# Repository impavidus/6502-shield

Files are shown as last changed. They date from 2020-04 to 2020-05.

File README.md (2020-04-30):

# 6502-shield

An Arduino shield that provides a 6502 cpu, ram, rom, and pio compactly.

## Project Status

I'm about to order the first prototype PCBs from OSH Park.  That means this PCB is completely untested and quite likely may burst into flames when powered on.  However, I am by no means here to tell you how to live your life so if you want to make one... =)

## Introduction

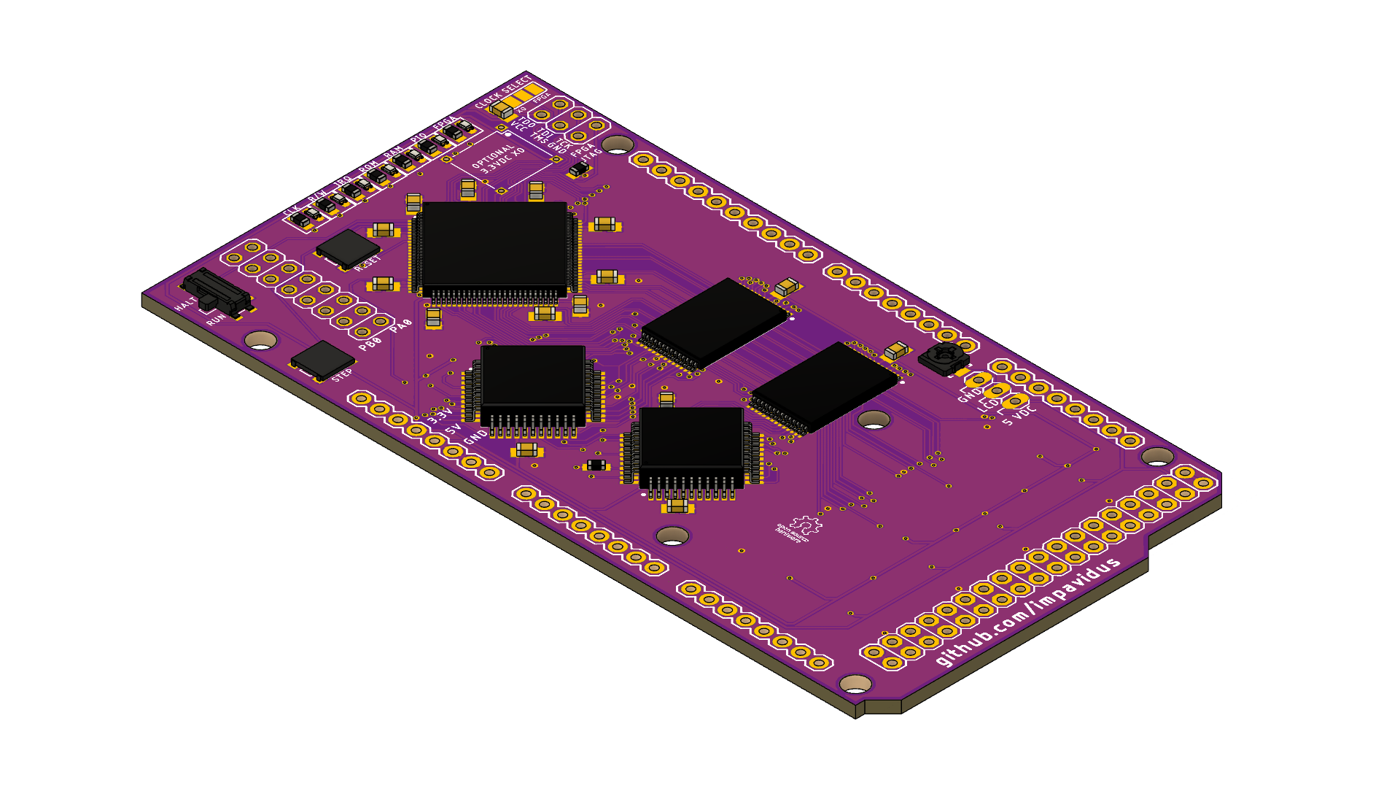
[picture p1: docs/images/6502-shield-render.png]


The 6502 shield provides (err will provide) most of the major components needed to implement a 6502 based computer.  Some of the key features.  This is aspirational and subject to change.

* Fully static design allows for single step execution of programs
* W65C02S - 8 bit CPU, W65C22 PIO controller, AT28BV256 256K EEPROM, AS6C62256 256K SRAM
* Full access to PIO PORTA and PORTB via header
* LCD header with potentiometer provides power, ground, and contrast adjust
* All components are leaded and reachable with mini-grabbers
* Support for optional DIP-8/4 3.3V External Crystal Oscillator
* Clock select jumper allows board to run from Internal FPGA clock or External XO
* LED status indicators for R/W, IRQ, CLK pins
* LED status indicators show when a devices address space is being accessed by the CPU (RAM/ROM/PIO/FPGA)
* FPGA manages chip enables based on user defined memory map.
* EEPROM write protection for EEPROM address space.
* EEPROM is programmed directly by Arduino asserting EEPROM_PGM line. This also disables EEPROM write protection in place during normal operation.
* DMA access from the Arduino to the 256K SRAM supported by asserting DMA line.
* FPGA clock supports run/halt/step via on-board push-button and slide switches.

## PCB

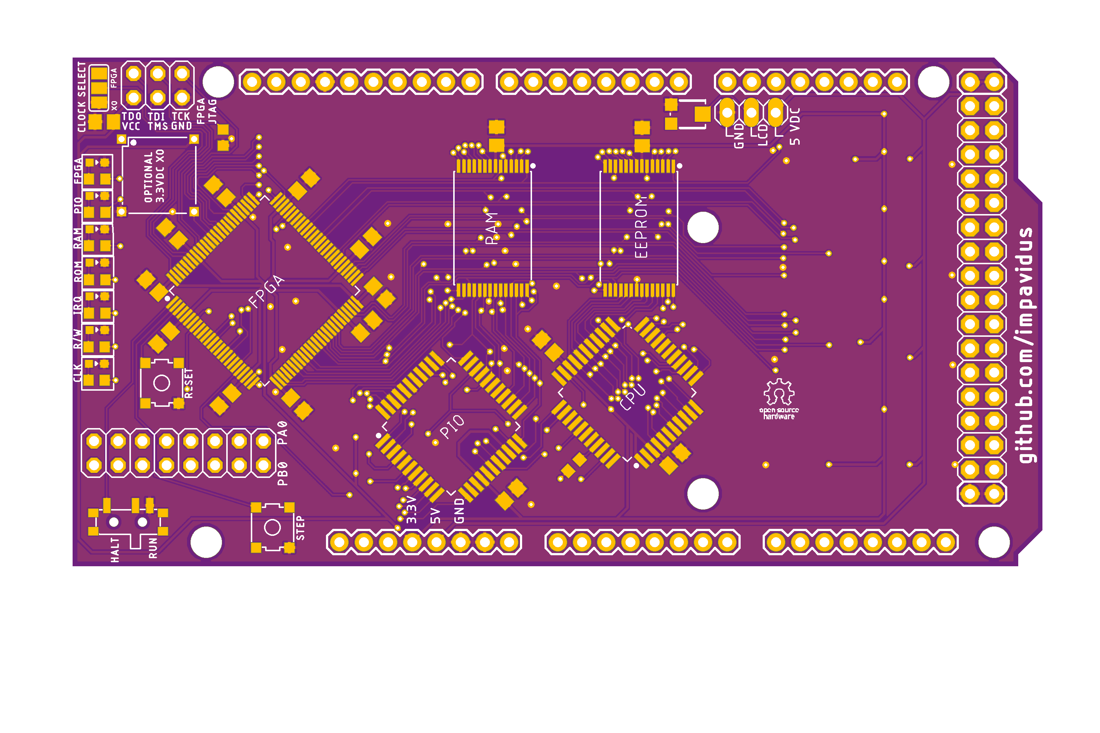
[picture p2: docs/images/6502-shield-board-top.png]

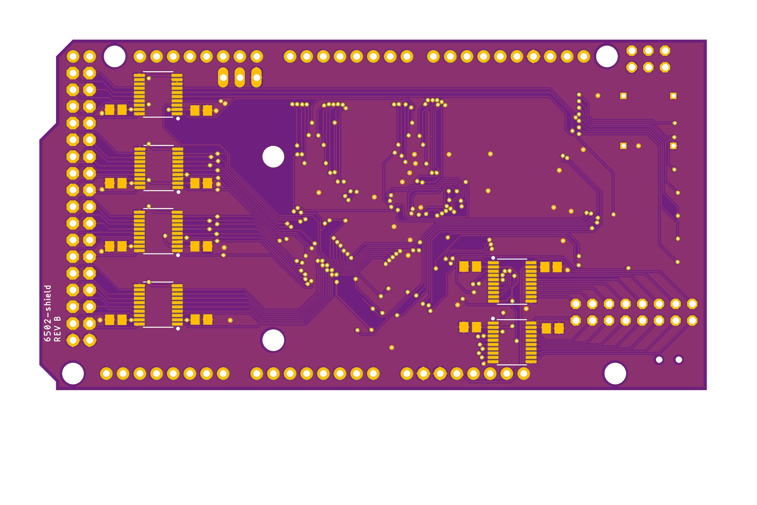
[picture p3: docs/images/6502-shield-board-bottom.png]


## Schematic

A PDF version of the schematic is <a href="docs/6502-shield-schematic.pdf">here</a>.

## System Block Diagram

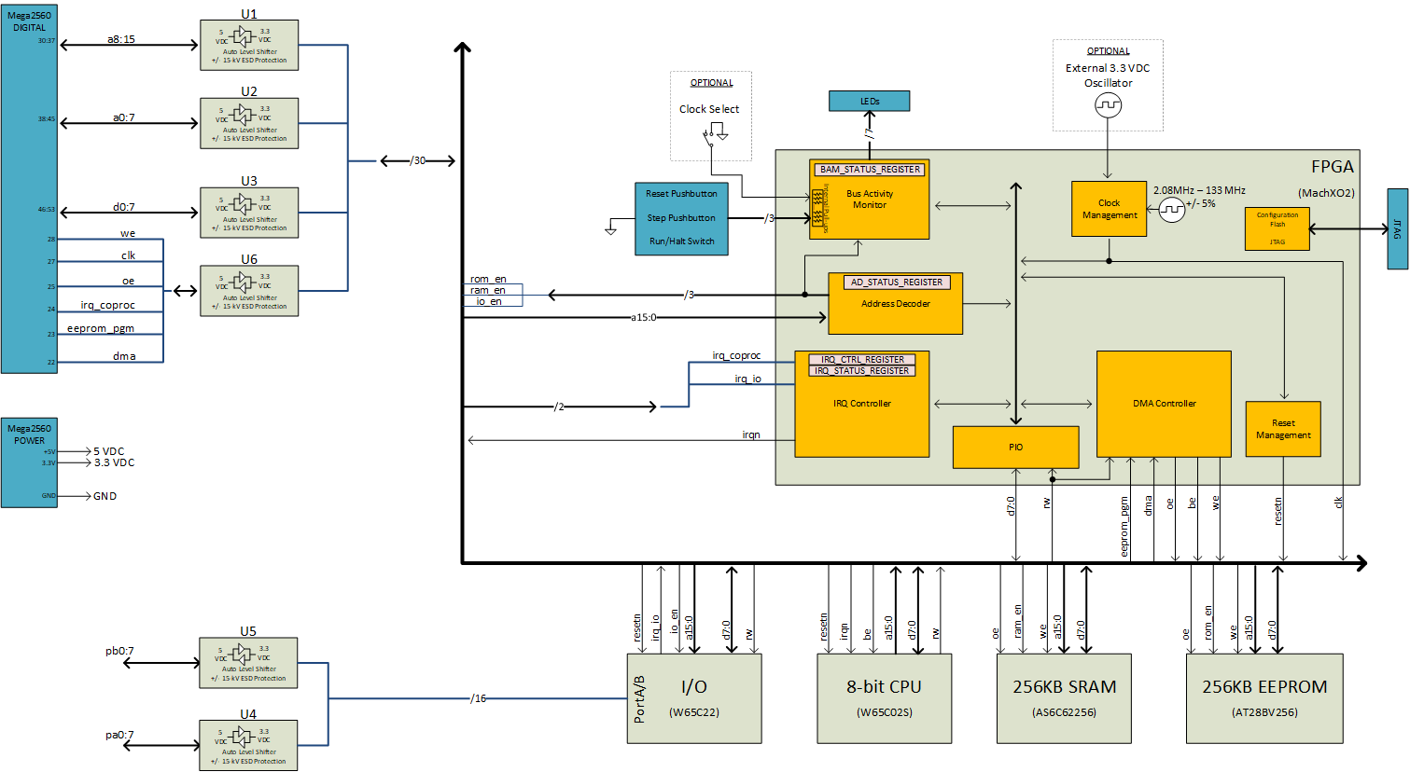
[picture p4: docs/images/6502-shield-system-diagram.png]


## Source Files

All of the schematic capture and board layout work was done with Eagle.  The component libraries used, .sch, and .brd files are provided.

## CAM Files

All CAM files needed for PCB manufacturing including silkscreens, drills, etc. are provided.  In addition pick and place files and a Bill of Materials is provided in the CAMOutputs/Assembly folder.

## Models

The 3d model was done with AutoDesk Fusion.  The source file as well as .STEP file for the completed shield is provided.

## FPGA

The FPGA work is all going to be done in VHDL.  Once I begin writing it, I will add all of the source files, testbenches, etc. to the repository.

## 6502 Code

Also plan to provide some simple example assembly that demonstrates all the boards functions are working.  This will also be added to the repository.

## Acknowledgements

* Ben Eater - His breadboard computer projects are making homebrew cool again.  Ben's work heavily influenced my decision to attempt this project as well as inspiring me to make it all open and available for anyone.  If you're just getting started, please start with Ben's site, even if you don't build the breadboards yourself (but you should if at all possible) - seriously -  Thanks Ben.  < http://eater.net >

* Daryl Rictor - Thank you Daryl for sharing your Memory Decoder GAL based design to achieve a flexible memory map.  I am applying your approach in the FPGA of my design. < http://sbc.rictor.org/decoder.html >

* r/beneater - Pretty cool community even though I'm a lurker.  Seeing everybody else's builds made me give it a try, thanks for that everyone.  https://reddit.com/r/beneater

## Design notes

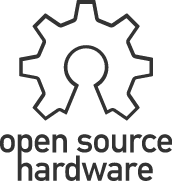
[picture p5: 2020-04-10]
eagle-pcb/external-models/oshw.png

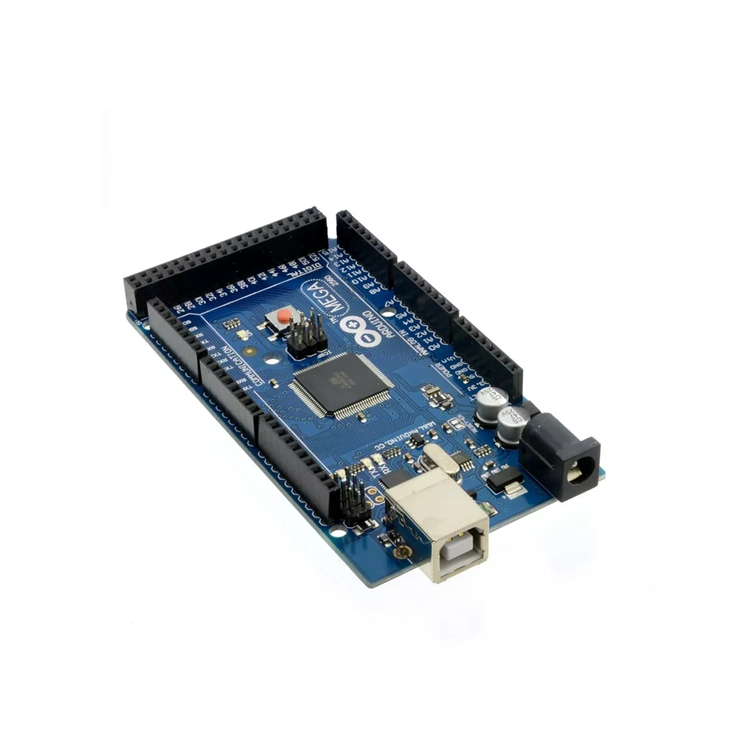
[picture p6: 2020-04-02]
ext-cad/arduino-mega-2560-r3/Arduino MEGA 2560 R3.jpg

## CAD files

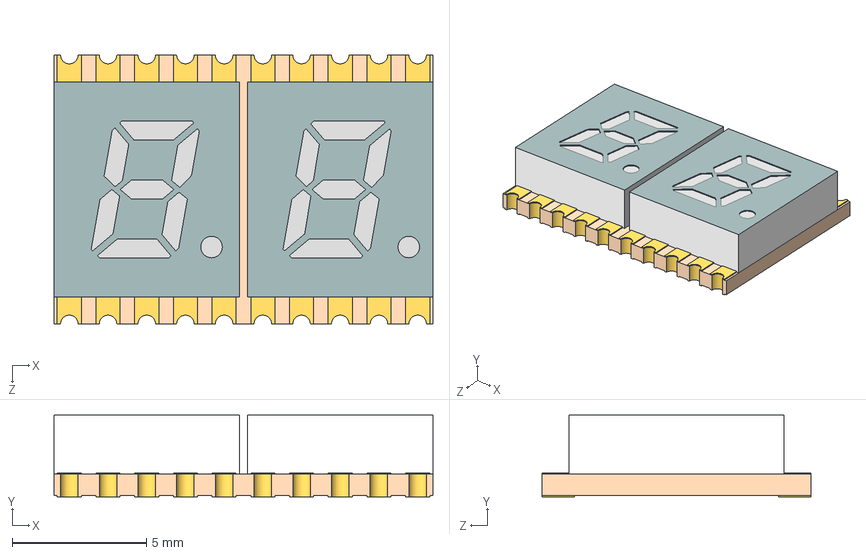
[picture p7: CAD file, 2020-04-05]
ext-cad/ACDX02-41.STEP
14.1 x 3.05 x 10.0 mm

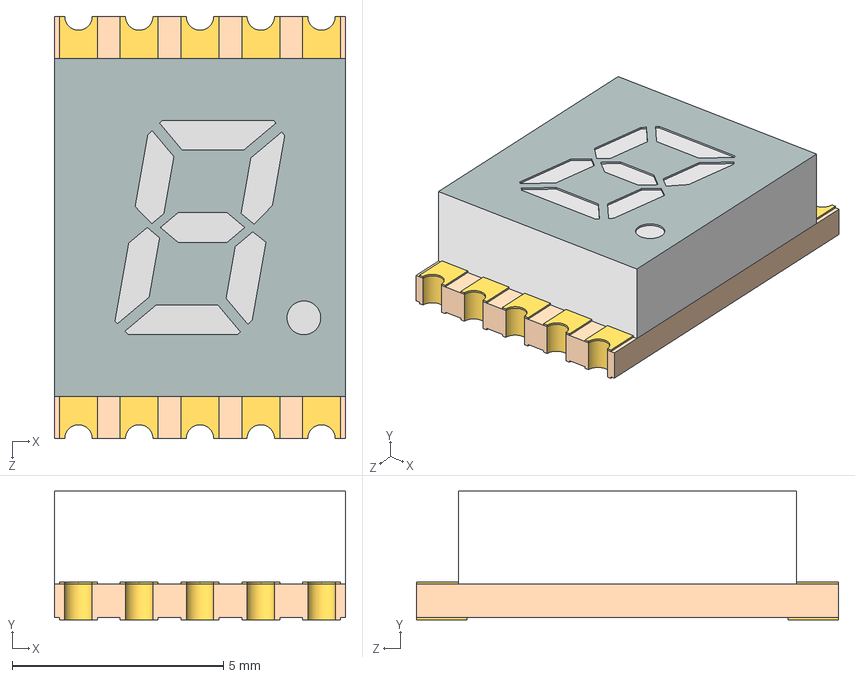
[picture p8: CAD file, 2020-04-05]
ext-cad/ACSX02-41.STEP
6.90 x 3.05 x 10.0 mm

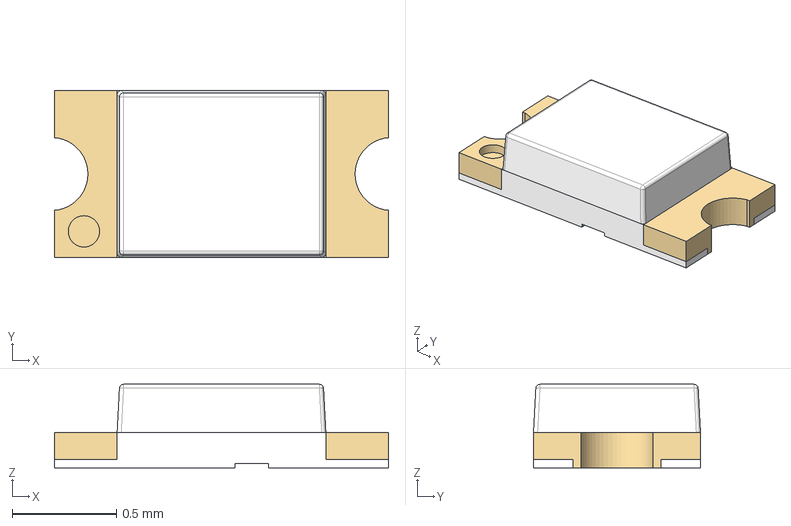
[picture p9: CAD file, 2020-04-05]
ext-cad/WL-SMCD-0603_rev1.stp
1.60 x 0.8 x 0.4 mm
housing
cover
base-oa0
base

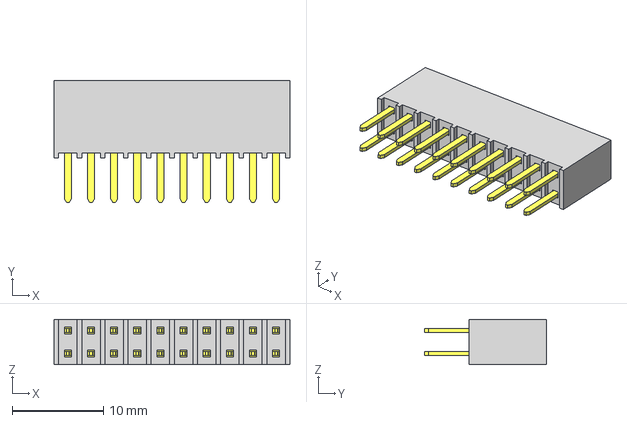
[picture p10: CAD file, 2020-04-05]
ext-cad/SSW-110-02-T-D.stp
25.9 x 13.4 x 4.95 mm
_T1SSW-110-02-T-D
_P2SSW-110-02-T-D

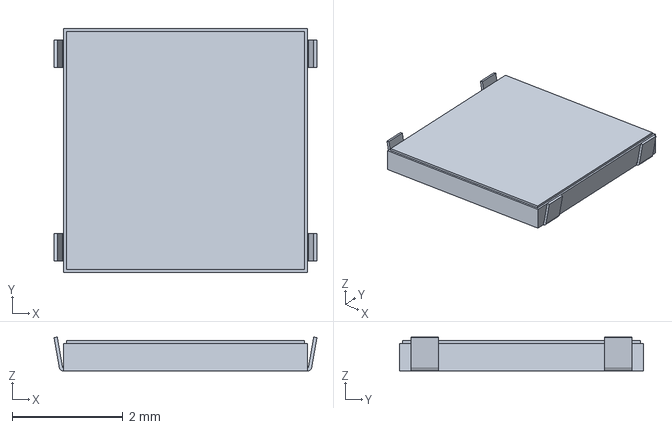
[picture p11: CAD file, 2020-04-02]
ext-cad/c-2337234-1-a-3d.stp
4.75 x 4.40 x 0.613 mm

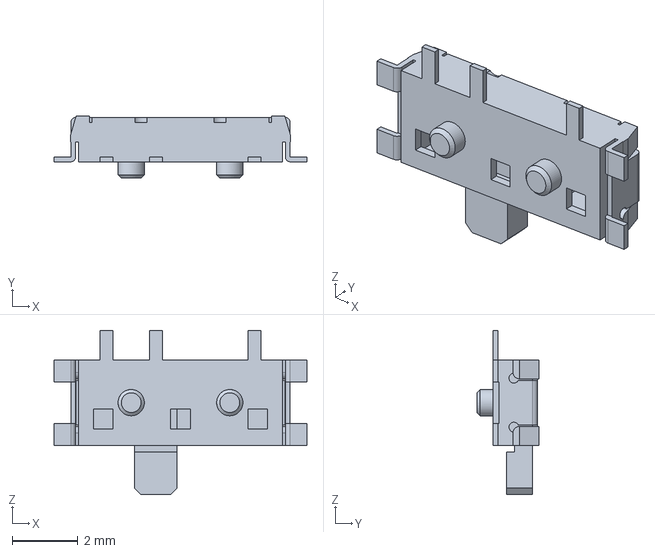
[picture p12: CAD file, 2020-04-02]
ext-cad/PCM12SMTR.stp
7.70 x 1.90 x 5.00 mm

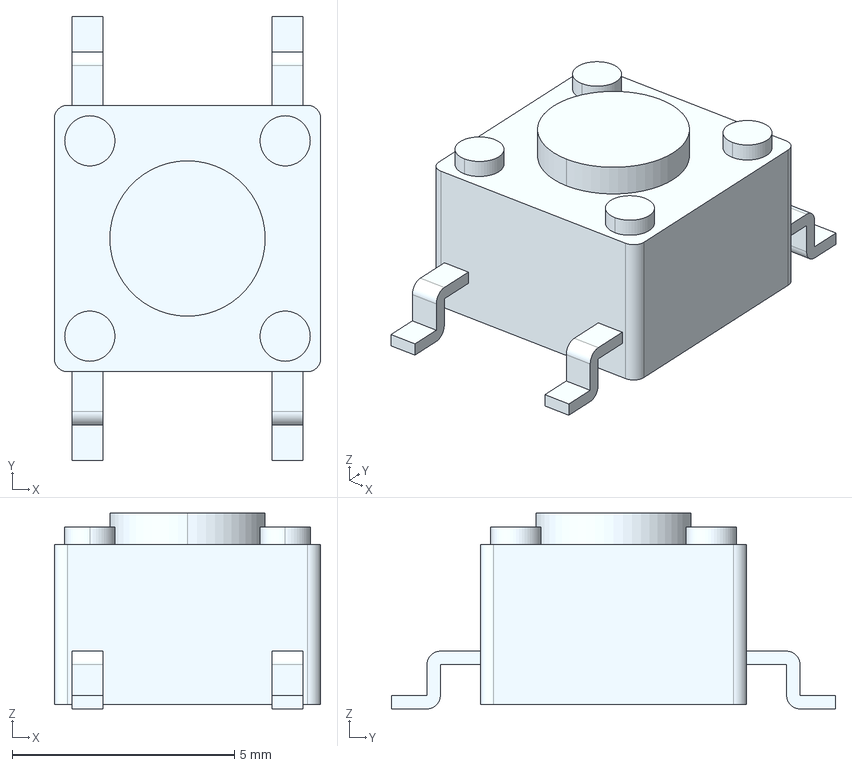
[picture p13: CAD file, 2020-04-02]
ext-cad/c-1977223-6-a-3d.stp
6.00 x 10.0 x 4.41 mm

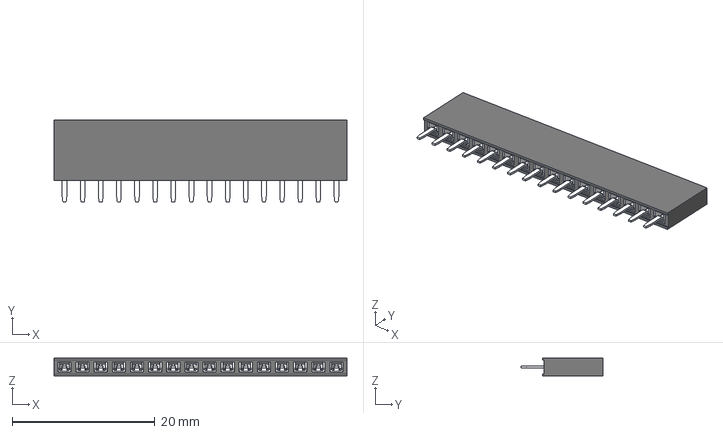
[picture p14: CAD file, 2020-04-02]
ext-cad/m20-7821646_asm.stp
41.0 x 11.5 x 2.50 mm
M20-78216_MOULD
M20-782_CONTACT x 16

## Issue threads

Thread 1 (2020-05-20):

TDI/TMS/TCK are wrong on silkscreen

impavidus, 2020-05-20:
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

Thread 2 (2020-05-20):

Run/Halt Switch is Incorrect

impavidus, 2020-05-20:
Gnd should be connected to pin 2 of the spdt switch used to control run/halt but is connected to pin 3.  Suspect a mistake in the schematic or the library component.  Jumper pins 2+3 of switch as workaround.

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

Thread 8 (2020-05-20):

Consider moving bus_clk on DIO header to support Mega2560 external interrupts

impavidus, 2020-05-20:
The following digital pins on the 2560 support external interupts: 2, 3, 18, 19, 20, 21

https://www.arduino.cc/reference/en/language/functions/external-interrupts/attachinterrupt/

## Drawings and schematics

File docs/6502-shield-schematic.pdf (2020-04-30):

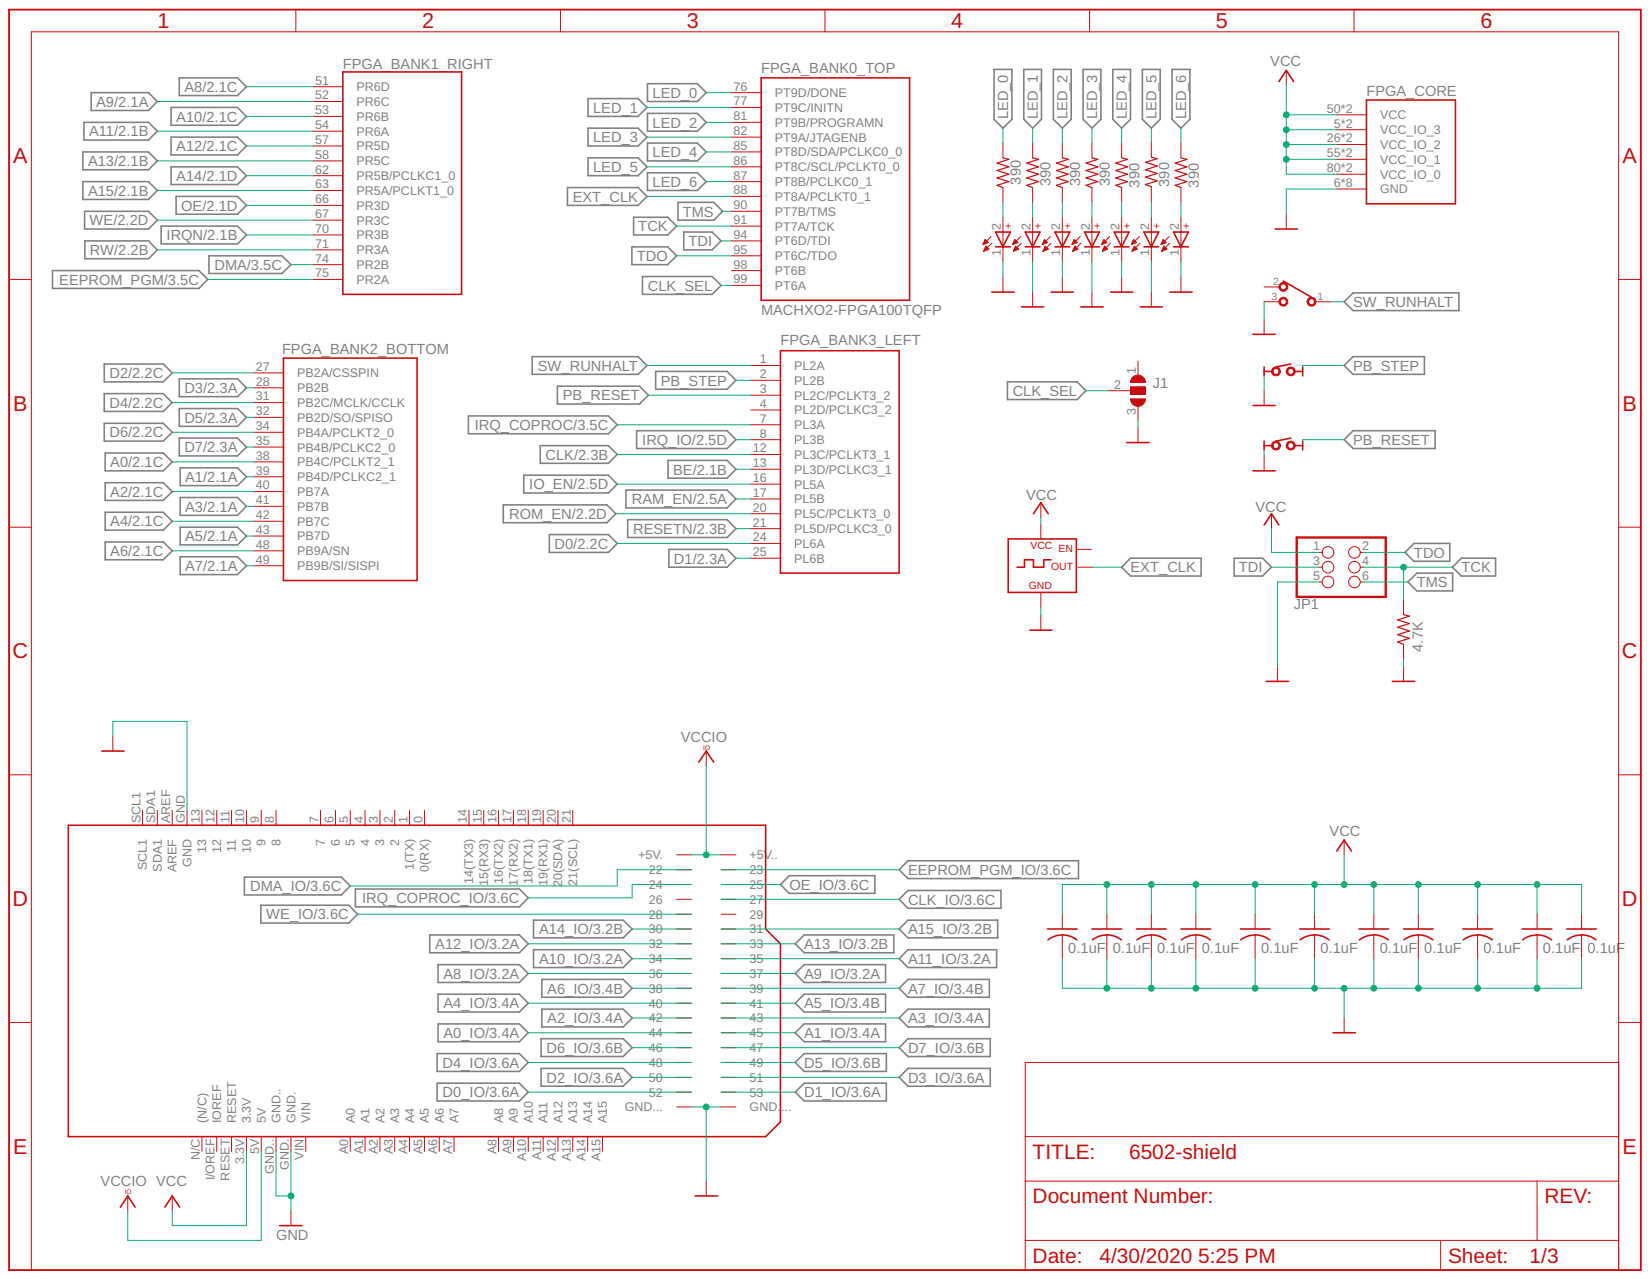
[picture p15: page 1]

VCC EN OUT GND

SCL1 SCL1 SDA1 SDA1 AREF AREF GND GND

VIN GND. GND. GND.. GND.. 5V

Document Number: | REV:

Date: 4/30/2020 5:25 PM | Sheet: 1/3

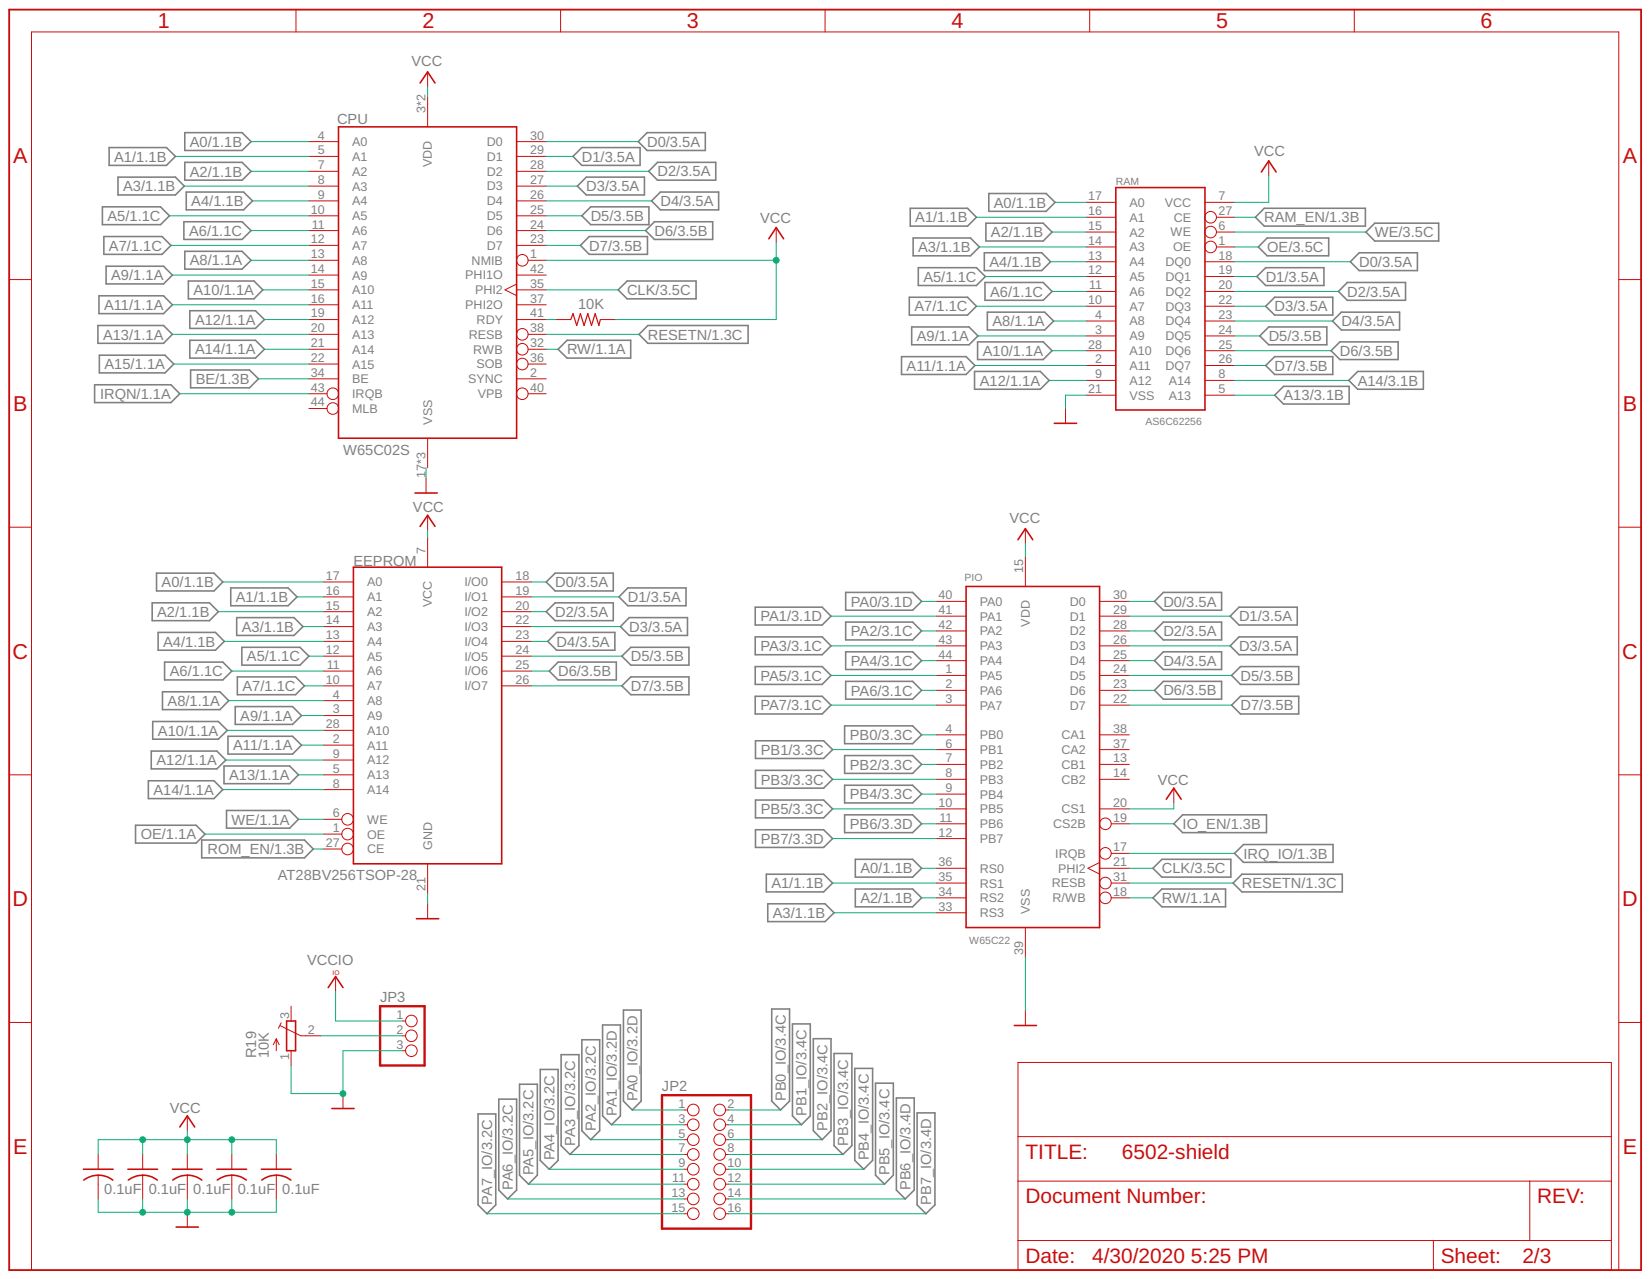
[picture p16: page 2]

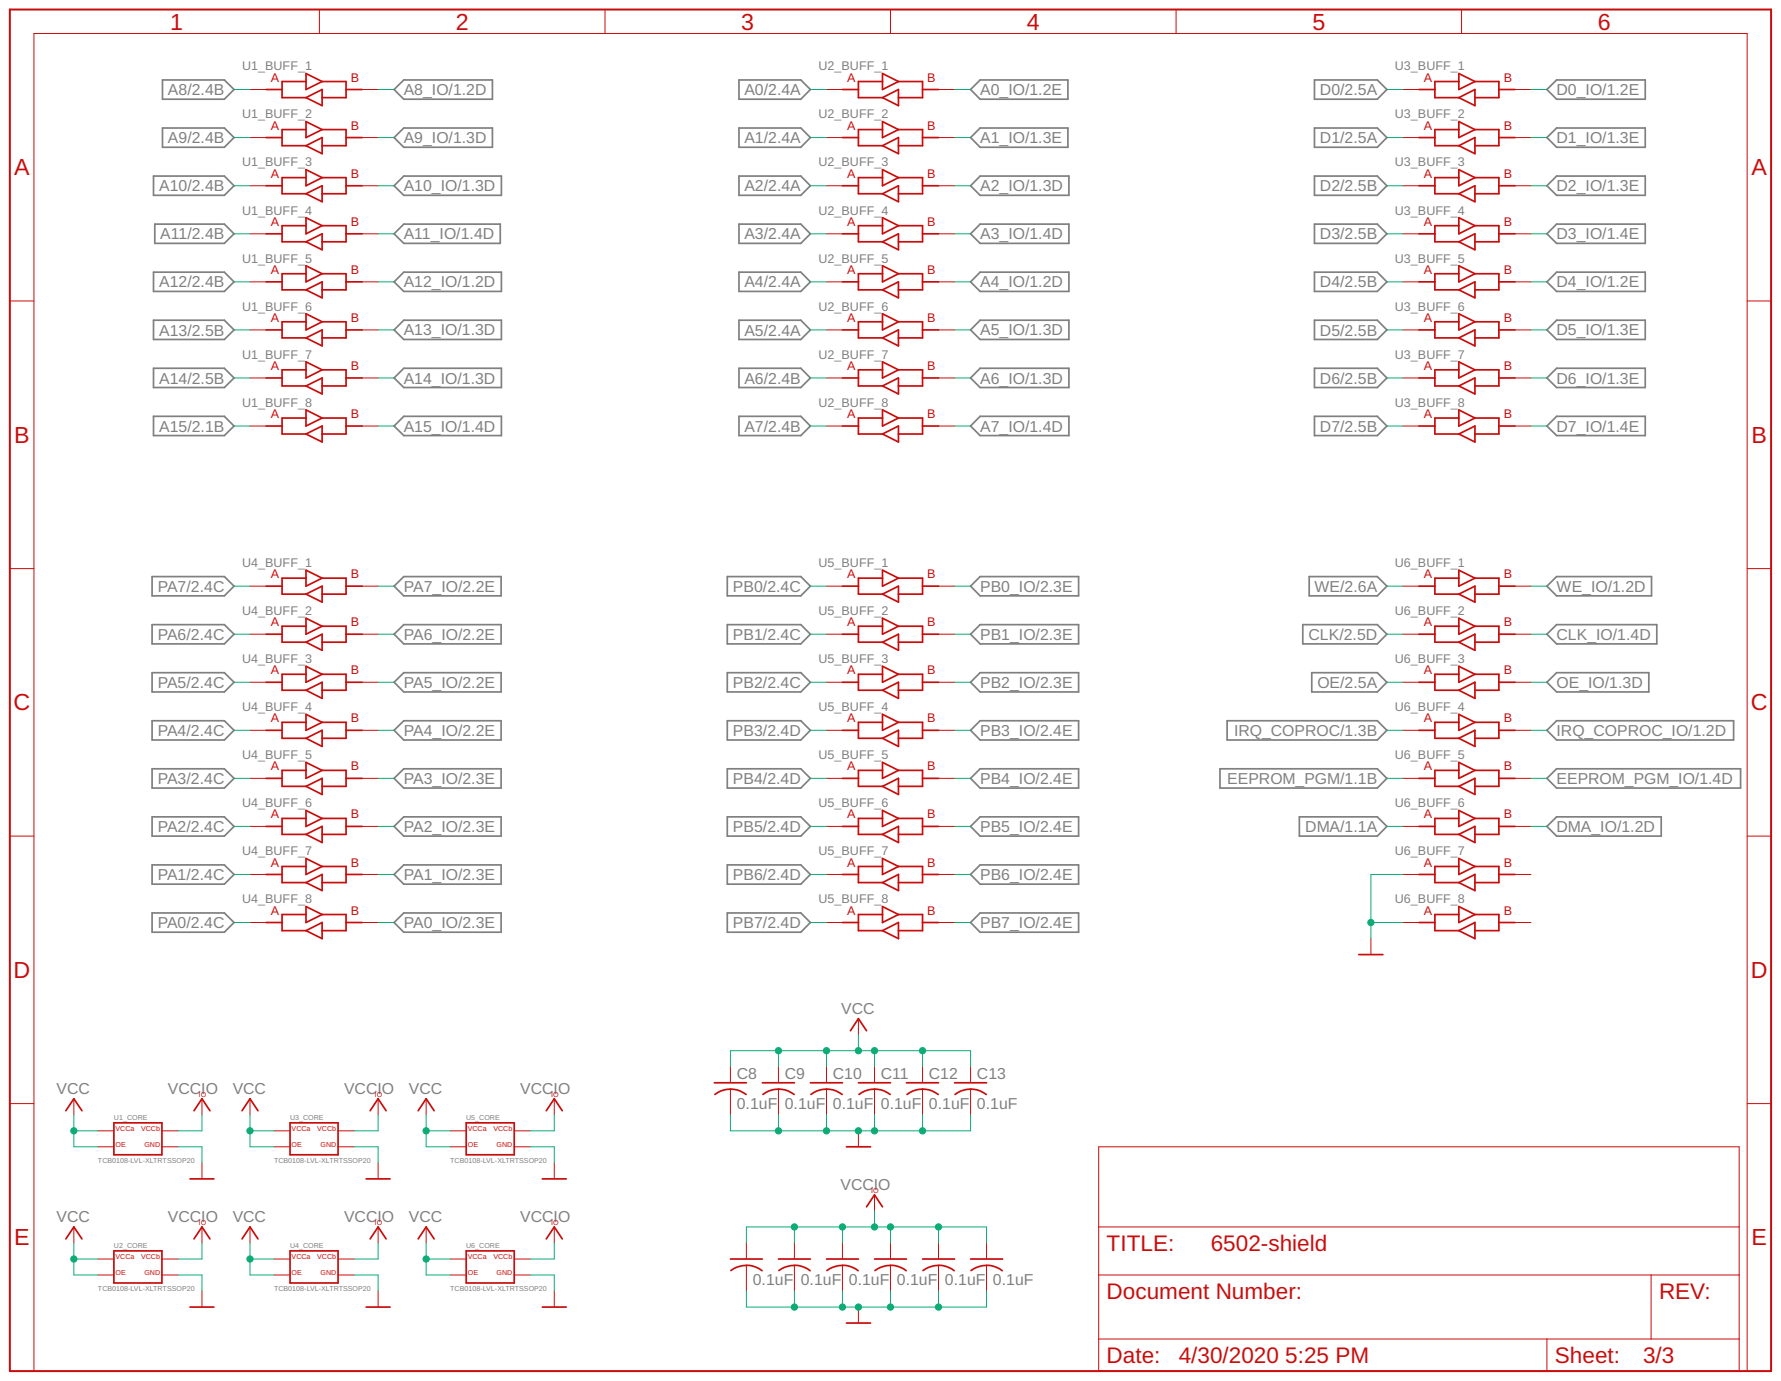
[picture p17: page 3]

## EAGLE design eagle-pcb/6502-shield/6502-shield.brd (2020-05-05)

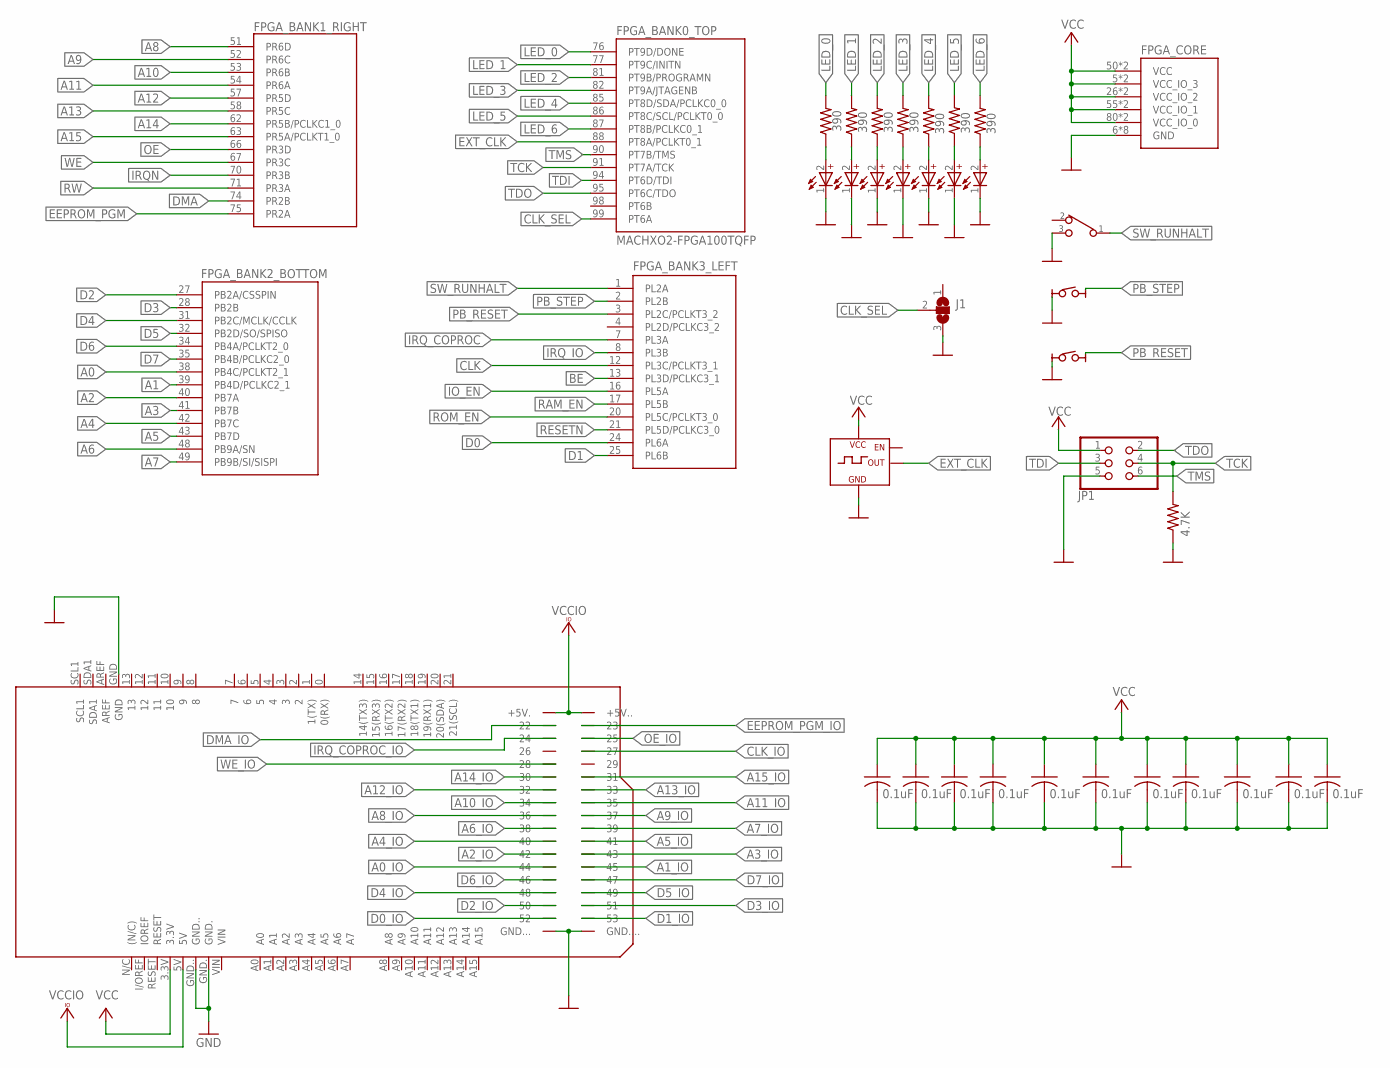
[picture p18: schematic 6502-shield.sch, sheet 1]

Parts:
C1, C2, C3, C4, C5, C6, C7, C20, C21, C22, C23: 0.1uF; C0805
D1, D2, D3, D4, D5, D6, D7: RED; WL-SMCD_0603
EXT_XO: CRYSTAL-OSC-DIP8/4; DIP8/4
FPGA: MACHXO2-FPGA100TQFP; QFP50P1600X1600X160-100N
J1: SJ2W; SJ_2
JP1: PINHD-2X3; 2X03
PB_RESET: MCSLPT4644B1TR-TACT-SW; MCSLPT4644B1TR-TACT-SW-NEW
PB_STEP: MCSLPT4644B1TR-TACT-SW; MCSLPT4644B1TR-TACT-SW-NEW
PCB1: ARDUINO_MEGA2560
R2, R4, R5, R6, R7, R8, R9: 390; R0603
R3: 4.7K; R0603
SW_RUNHALT: PCM12SMTR-SPDT-RIGHT-ANG; PCM12SMTR

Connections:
A0: FPGA.38 (PB4C/PCLKT2_1); also elsewhere on the board
A0_IO: PCB1.44; also elsewhere on the board
A1: FPGA.39 (PB4D/PCLKC2_1); also elsewhere on the board
A1_IO: PCB1.45; also elsewhere on the board
A2: FPGA.40 (PB7A); also elsewhere on the board
A2_IO: PCB1.42; also elsewhere on the board
A3: FPGA.41 (PB7B); also elsewhere on the board
A3_IO: PCB1.43; also elsewhere on the board
A4: FPGA.42 (PB7C); also elsewhere on the board
A4_IO: PCB1.40; also elsewhere on the board
A5: FPGA.43 (PB7D); also elsewhere on the board
A5_IO: PCB1.41; also elsewhere on the board
A6: FPGA.48 (PB9A/SN); also elsewhere on the board
A6_IO: PCB1.38; also elsewhere on the board
A7: FPGA.49 (PB9B/SI/SISPI); also elsewhere on the board
A7_IO: PCB1.39; also elsewhere on the board
A8: FPGA.51 (PR6D); also elsewhere on the board
A8_IO: PCB1.36; also elsewhere on the board
A9: FPGA.52 (PR6C); also elsewhere on the board
A9_IO: PCB1.37; also elsewhere on the board
A10: FPGA.53 (PR6B); also elsewhere on the board
A10_IO: PCB1.34; also elsewhere on the board
A11: FPGA.54 (PR6A); also elsewhere on the board
A11_IO: PCB1.35; also elsewhere on the board
A12: FPGA.57 (PR5D); also elsewhere on the board
A12_IO: PCB1.32; also elsewhere on the board
A13: FPGA.58 (PR5C); also elsewhere on the board
A13_IO: PCB1.33; also elsewhere on the board
A14: FPGA.62 (PR5B/PCLKC1_0); also elsewhere on the board
A14_IO: PCB1.30; also elsewhere on the board
A15: FPGA.63 (PR5A/PCLKT1_0); also elsewhere on the board
A15_IO: PCB1.31; also elsewhere on the board
BE: FPGA.13 (PL3D/PCLKC3_1); also elsewhere on the board
CLK: FPGA.12 (PL3C/PCLKT3_1); also elsewhere on the board
CLK_IO: PCB1.27; also elsewhere on the board
CLK_SEL: FPGA.99 (PT6A), J1.2
D0: FPGA.24 (PL6A); also elsewhere on the board
D0_IO: PCB1.52; also elsewhere on the board
D1: FPGA.25 (PL6B); also elsewhere on the board
D1_IO: PCB1.53; also elsewhere on the board
D2: FPGA.27 (PB2A/CSSPIN); also elsewhere on the board
D2_IO: PCB1.50; also elsewhere on the board
D3: FPGA.28 (PB2B); also elsewhere on the board
D3_IO: PCB1.51; also elsewhere on the board
D4: FPGA.31 (PB2C/MCLK/CCLK); also elsewhere on the board
D4_IO: PCB1.48; also elsewhere on the board
D5: FPGA.32 (PB2D/SO/SPISO); also elsewhere on the board
D5_IO: PCB1.49; also elsewhere on the board
D6: FPGA.34 (PB4A/PCLKT2_0); also elsewhere on the board
D6_IO: PCB1.46; also elsewhere on the board
D7: FPGA.35 (PB4B/PCLKC2_0); also elsewhere on the board
D7_IO: PCB1.47; also elsewhere on the board
DMA: FPGA.74 (PR2B); also elsewhere on the board
DMA_IO: PCB1.22; also elsewhere on the board
EEPROM_PGM: FPGA.75 (PR2A); also elsewhere on the board
EEPROM_PGM_IO: PCB1.23; also elsewhere on the board
EXT_CLK: EXT_XO.5 (OUT), FPGA.88 (PT8A/PCLKT0_1)
GND: C1.2, C2.2, C3.2, C4.2, C5.2, C6.2, C7.2, C20.2, C21.2, C22.2, C23.2, D1.1 (C), D2.1 (C), D3.1 (C), D4.1 (C), D5.1 (C), D6.1 (C), D7.1 (C), EXT_XO.4 (GND), FPGA.6 (GND), FPGA.22 (GND), FPGA.33 (GND), FPGA.44 (GND), FPGA.56 (GND), FPGA.72 (GND), FPGA.79 (GND), FPGA.92 (GND), J1.3, JP1.5, PB_RESET.T2, PB_STEP.T2, PCB1.GND, PCB1.GND., PCB1.GND.., PCB1.GND..., PCB1.GND...., R3.1, SW_RUNHALT.3; also elsewhere on the board
IO_EN: FPGA.16 (PL5A); also elsewhere on the board
IRQN: FPGA.70 (PR3B); also elsewhere on the board
IRQ_COPROC: FPGA.7 (PL3A); also elsewhere on the board
IRQ_COPROC_IO: PCB1.24; also elsewhere on the board
IRQ_IO: FPGA.8 (PL3B); also elsewhere on the board
LED_0: FPGA.76 (PT9D/DONE), R5.2
LED_1: FPGA.77 (PT9C/INITN), R6.2
LED_2: FPGA.81 (PT9B/PROGRAMN), R7.2
LED_3: FPGA.82 (PT9A/JTAGENB), R8.2
LED_4: FPGA.85 (PT8D/SDA/PCLKC0_0), R9.2
LED_5: FPGA.86 (PT8C/SCL/PCLKT0_0), R4.2
LED_6: FPGA.87 (PT8B/PCLKC0_1), R2.2
unnamed: D1.2 (A), R5.1
unnamed: D2.2 (A), R6.1
unnamed: D5.2 (A), R7.1
unnamed: D4.2 (A), R8.1
unnamed: D3.2 (A), R9.1
unnamed: D6.2 (A), R4.1
unnamed: D7.2 (A), R2.1
OE: FPGA.66 (PR3D); also elsewhere on the board
OE_IO: PCB1.25; also elsewhere on the board
PB_RESET: FPGA.3 (PL2C/PCLKT3_2), PB_RESET.T3
PB_STEP: FPGA.2 (PL2B), PB_STEP.T3
RAM_EN: FPGA.17 (PL5B); also elsewhere on the board
RESETN: FPGA.21 (PL5D/PCLKC3_0); also elsewhere on the board
ROM_EN: FPGA.20 (PL5C/PCLKT3_0); also elsewhere on the board
RW: FPGA.71 (PR3A); also elsewhere on the board
SW_RUNHALT: FPGA.1 (PL2A), SW_RUNHALT.1
TCK: FPGA.91 (PT7A/TCK), JP1.4, R3.2
TDI: FPGA.94 (PT6D/TDI), JP1.3
TDO: FPGA.95 (PT6C/TDO), JP1.2
TMS: FPGA.90 (PT7B/TMS), JP1.6
VCC: C1.1, C2.1, C3.1, C4.1, C5.1, C6.1, C7.1, C20.1, C21.1, C22.1, C23.1, EXT_XO.8 (VCC), FPGA.5 (VCC_IO_3), FPGA.23 (VCC_IO_3), FPGA.26 (VCC_IO_2), FPGA.46 (VCC_IO_2), FPGA.50 (VCC), FPGA.55 (VCC_IO_1), FPGA.73 (VCC_IO_1), FPGA.80 (VCC_IO_0), FPGA.93 (VCC_IO_0), FPGA.100 (VCC), JP1.1, PCB1.3.3V; also elsewhere on the board
VCCIO: PCB1.5V, PCB1.5V. (+5V.), PCB1.5V.. (+5V..); also elsewhere on the board
WE: FPGA.67 (PR3C); also elsewhere on the board
WE_IO: PCB1.28; also elsewhere on the board

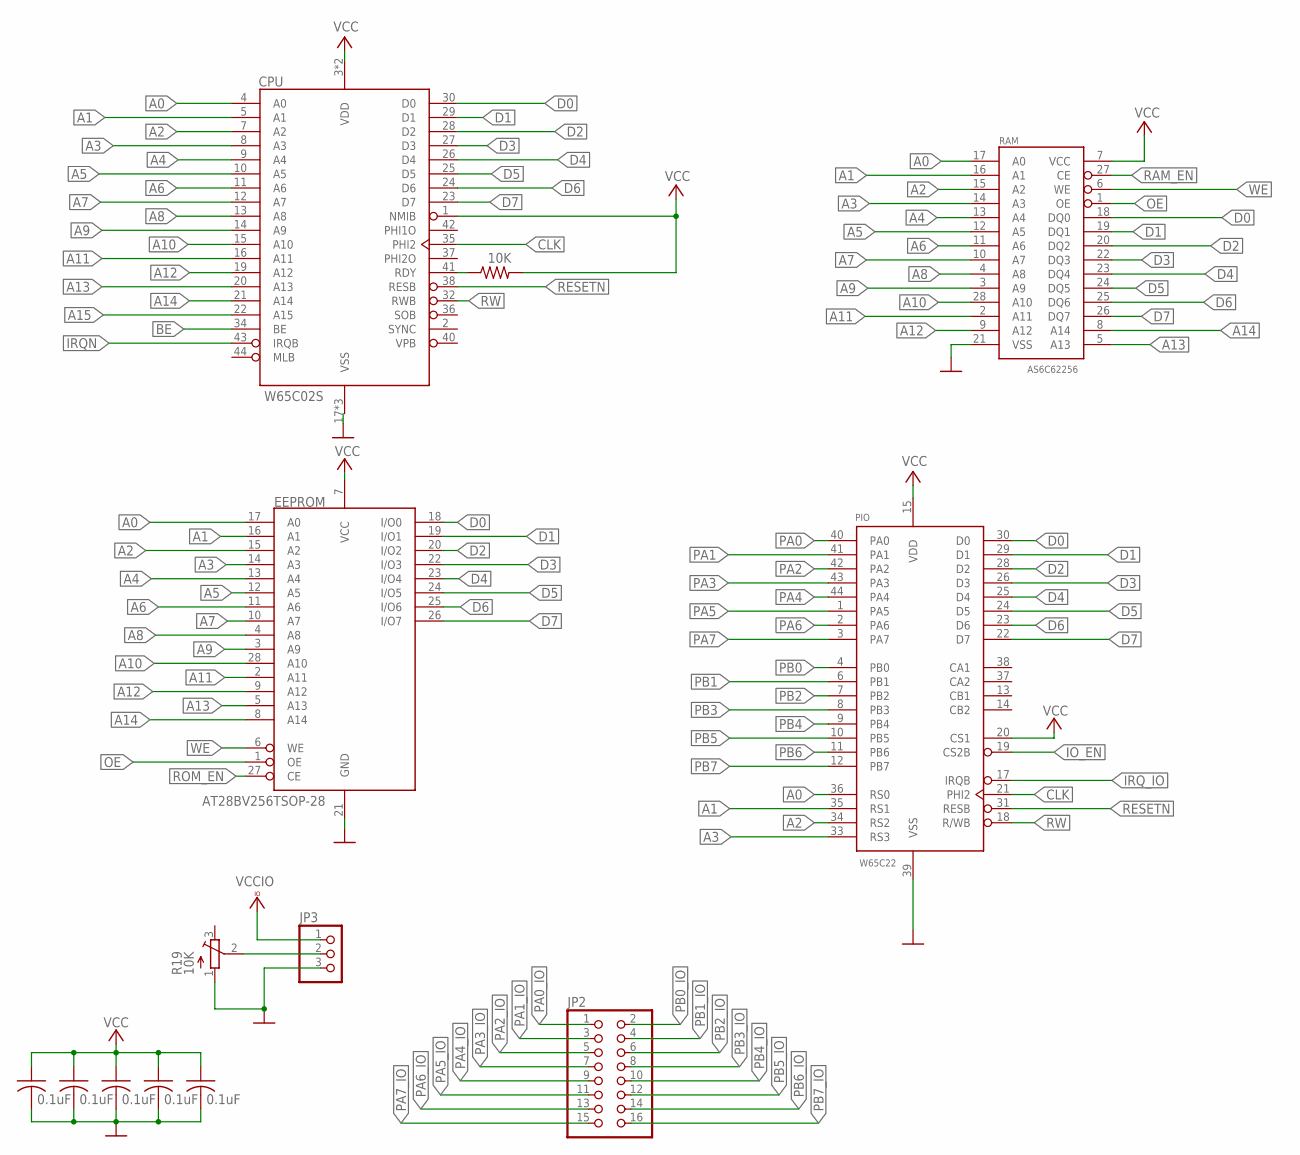
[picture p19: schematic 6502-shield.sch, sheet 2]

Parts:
C24, C25, C26, C27, C28: 0.1uF; C0805
CPU: W65C02S; QFP80P1320X1320X270-44N
EEPROM: AT28BV256TSOP-28; SOP55P1340X120-28N
JP2: PINHD-2X8; 2X08
JP3: PINHD-1X3; 1X03
PIO: W65C22; QFP80P1320X1320X270-44N
R18: 10K; R0603
R19: 10K; TC33X
RAM: AS6C62256; SOP55P1340X120-28N

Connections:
A0: CPU.4 (A0), EEPROM.17 (A0), PIO.36 (RS0), RAM.17 (A0); also elsewhere on the board
A1: CPU.5 (A1), EEPROM.16 (A1), PIO.35 (RS1), RAM.16 (A1); also elsewhere on the board
A2: CPU.7 (A2), EEPROM.15 (A2), PIO.34 (RS2), RAM.15 (A2); also elsewhere on the board
A3: CPU.8 (A3), EEPROM.14 (A3), PIO.33 (RS3), RAM.14 (A3); also elsewhere on the board
A4: CPU.9 (A4), EEPROM.13 (A4), RAM.13 (A4); also elsewhere on the board
A5: CPU.10 (A5), EEPROM.12 (A5), RAM.12 (A5); also elsewhere on the board
A6: CPU.11 (A6), EEPROM.11 (A6), RAM.11 (A6); also elsewhere on the board
A7: CPU.12 (A7), EEPROM.10 (A7), RAM.10 (A7); also elsewhere on the board
A8: CPU.13 (A8), EEPROM.4 (A8), RAM.4 (A8); also elsewhere on the board
A9: CPU.14 (A9), EEPROM.3 (A9), RAM.3 (A9); also elsewhere on the board
A10: CPU.15 (A10), EEPROM.28 (A10), RAM.28 (A10); also elsewhere on the board
A11: CPU.16 (A11), EEPROM.2 (A11), RAM.2 (A11); also elsewhere on the board
A12: CPU.19 (A12), EEPROM.9 (A12), RAM.9 (A12); also elsewhere on the board
A13: CPU.20 (A13), EEPROM.5 (A13), RAM.5 (A13); also elsewhere on the board
A14: CPU.21 (A14), EEPROM.8 (A14), RAM.8 (A14); also elsewhere on the board
A15: CPU.22 (A15); also elsewhere on the board
BE: CPU.34 (BE); also elsewhere on the board
CLK: CPU.35 (PHI2), PIO.21 (PHI2); also elsewhere on the board
D0: CPU.30 (D0), EEPROM.18 (I/O0), PIO.30 (D0), RAM.18 (DQ0); also elsewhere on the board
D1: CPU.29 (D1), EEPROM.19 (I/O1), PIO.29 (D1), RAM.19 (DQ1); also elsewhere on the board
D2: CPU.28 (D2), EEPROM.20 (I/O2), PIO.28 (D2), RAM.20 (DQ2); also elsewhere on the board
D3: CPU.27 (D3), EEPROM.22 (I/O3), PIO.26 (D3), RAM.22 (DQ3); also elsewhere on the board
D4: CPU.26 (D4), EEPROM.23 (I/O4), PIO.25 (D4), RAM.23 (DQ4); also elsewhere on the board
D5: CPU.25 (D5), EEPROM.24 (I/O5), PIO.24 (D5), RAM.24 (DQ5); also elsewhere on the board
D6: CPU.24 (D6), EEPROM.25 (I/O6), PIO.23 (D6), RAM.25 (DQ6); also elsewhere on the board
D7: CPU.23 (D7), EEPROM.26 (I/O7), PIO.22 (D7), RAM.26 (DQ7); also elsewhere on the board
GND: C24.2, C25.2, C26.2, C27.2, C28.2, EEPROM.21 (GND), JP3.3, PIO.39 (VSS), R19.1 (A), RAM.21 (VSS); also elsewhere on the board
IO_EN: PIO.19 (CS2B); also elsewhere on the board
IRQN: CPU.43 (IRQB); also elsewhere on the board
IRQ_IO: PIO.17 (IRQB); also elsewhere on the board
unnamed: CPU.41 (RDY), R18.1
unnamed: JP3.2, R19.2 (S)
OE: EEPROM.1 (OE), RAM.1 (OE); also elsewhere on the board
PA0: PIO.40 (PA0); also elsewhere on the board
PA0_IO: JP2.1; also elsewhere on the board
PA1: PIO.41 (PA1); also elsewhere on the board
PA1_IO: JP2.3; also elsewhere on the board
PA2: PIO.42 (PA2); also elsewhere on the board
PA2_IO: JP2.5; also elsewhere on the board
PA3: PIO.43 (PA3); also elsewhere on the board
PA3_IO: JP2.7; also elsewhere on the board
PA4: PIO.44 (PA4); also elsewhere on the board
PA4_IO: JP2.9; also elsewhere on the board
PA5: PIO.1 (PA5); also elsewhere on the board
PA5_IO: JP2.11; also elsewhere on the board
PA6: PIO.2 (PA6); also elsewhere on the board
PA6_IO: JP2.13; also elsewhere on the board
PA7: PIO.3 (PA7); also elsewhere on the board
PA7_IO: JP2.15; also elsewhere on the board
PB0: PIO.4 (PB0); also elsewhere on the board
PB0_IO: JP2.2; also elsewhere on the board
PB1: PIO.6 (PB1); also elsewhere on the board
PB1_IO: JP2.4; also elsewhere on the board
PB2: PIO.7 (PB2); also elsewhere on the board
PB2_IO: JP2.6; also elsewhere on the board
PB3: PIO.8 (PB3); also elsewhere on the board
PB3_IO: JP2.8; also elsewhere on the board
PB4: PIO.9 (PB4); also elsewhere on the board
PB4_IO: JP2.10; also elsewhere on the board
PB5: PIO.10 (PB5); also elsewhere on the board
PB5_IO: JP2.12; also elsewhere on the board
PB6: PIO.11 (PB6); also elsewhere on the board
PB6_IO: JP2.14; also elsewhere on the board
PB7: PIO.12 (PB7); also elsewhere on the board
PB7_IO: JP2.16; also elsewhere on the board
RAM_EN: RAM.27 (CE); also elsewhere on the board
RESETN: CPU.38 (RESB), PIO.31 (RESB); also elsewhere on the board
ROM_EN: EEPROM.27 (CE); also elsewhere on the board
RW: CPU.32 (RWB), PIO.18 (R/WB); also elsewhere on the board
VCC: C24.1, C25.1, C26.1, C27.1, C28.1, CPU.1 (NMIB), CPU.3 (VDD), CPU.31 (VDD), EEPROM.7 (VCC), PIO.15 (VDD), PIO.20 (CS1), R18.2, RAM.7 (VCC); also elsewhere on the board
VCCIO: JP3.1; also elsewhere on the board
WE: EEPROM.6 (WE), RAM.6 (WE); also elsewhere on the board

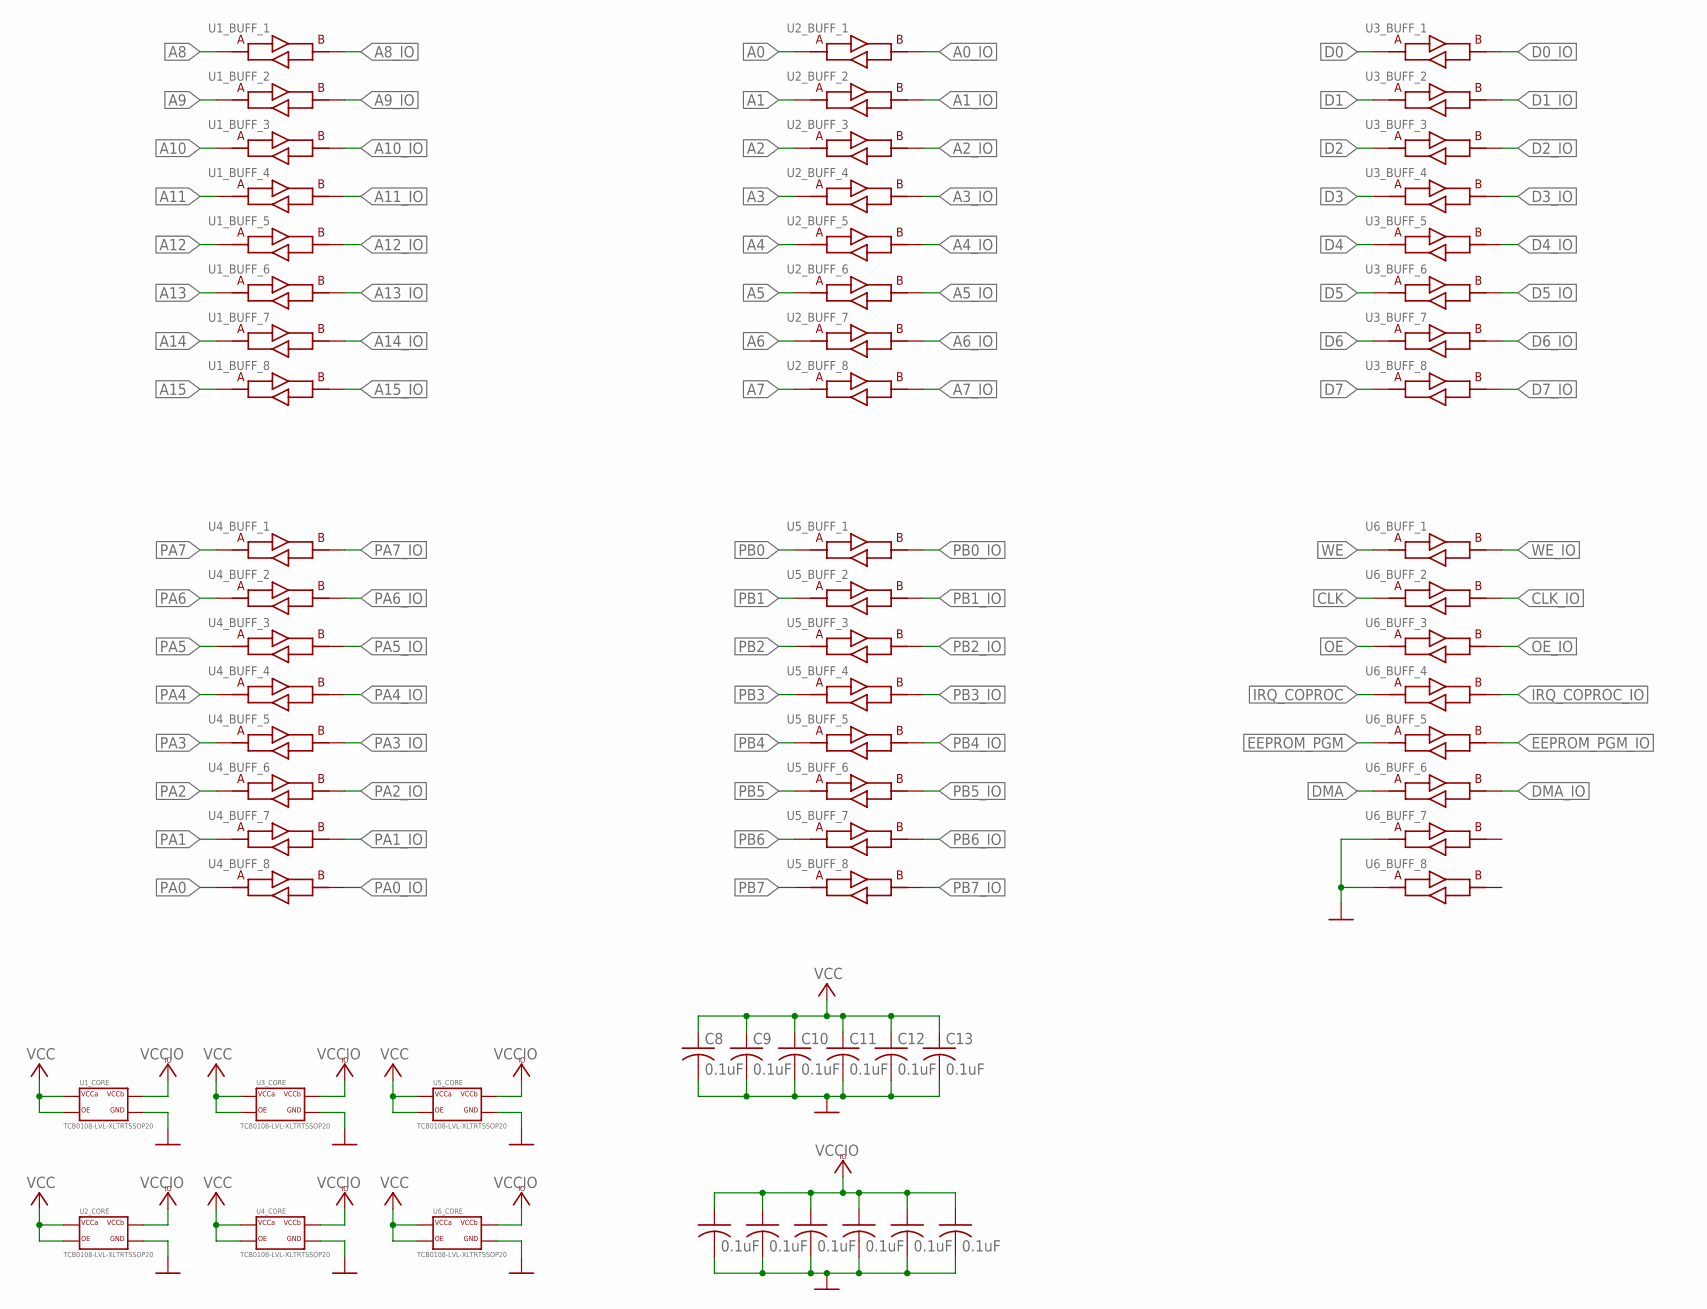
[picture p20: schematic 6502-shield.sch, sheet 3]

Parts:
C8, C9, C10, C11, C12, C13, C14, C15, C16, C17, C18, C19: 0.1uF; C0805
U1, U2, U3, U4, U5, U6: TCB0108-LVL-XLTRTSSOP20; SOP65P640X120-20N

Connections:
A0: U2.1 (A); also elsewhere on the board
A0_IO: U2.20 (B); also elsewhere on the board
A1: U2.3 (A); also elsewhere on the board
A1_IO: U2.18 (B); also elsewhere on the board
A2: U2.4 (A); also elsewhere on the board
A2_IO: U2.17 (B); also elsewhere on the board
A3: U2.5 (A); also elsewhere on the board
A3_IO: U2.16 (B); also elsewhere on the board
A4: U2.6 (A); also elsewhere on the board
A4_IO: U2.15 (B); also elsewhere on the board
A5: U2.7 (A); also elsewhere on the board
A5_IO: U2.14 (B); also elsewhere on the board
A6: U2.8 (A); also elsewhere on the board
A6_IO: U2.13 (B); also elsewhere on the board
A7: U2.9 (A); also elsewhere on the board
A7_IO: U2.12 (B); also elsewhere on the board
A8: U1.1 (A); also elsewhere on the board
A8_IO: U1.20 (B); also elsewhere on the board
A9: U1.3 (A); also elsewhere on the board
A9_IO: U1.18 (B); also elsewhere on the board
A10: U1.4 (A); also elsewhere on the board
A10_IO: U1.17 (B); also elsewhere on the board
A11: U1.5 (A); also elsewhere on the board
A11_IO: U1.16 (B); also elsewhere on the board
A12: U1.6 (A); also elsewhere on the board
A12_IO: U1.15 (B); also elsewhere on the board
A13: U1.7 (A); also elsewhere on the board
A13_IO: U1.14 (B); also elsewhere on the board
A14: U1.8 (A); also elsewhere on the board
A14_IO: U1.13 (B); also elsewhere on the board
A15: U1.9 (A); also elsewhere on the board
A15_IO: U1.12 (B); also elsewhere on the board
CLK: U6.3 (A); also elsewhere on the board
CLK_IO: U6.18 (B); also elsewhere on the board
D0: U3.1 (A); also elsewhere on the board
D0_IO: U3.20 (B); also elsewhere on the board
D1: U3.3 (A); also elsewhere on the board
D1_IO: U3.18 (B); also elsewhere on the board
D2: U3.4 (A); also elsewhere on the board
D2_IO: U3.17 (B); also elsewhere on the board
D3: U3.5 (A); also elsewhere on the board
D3_IO: U3.16 (B); also elsewhere on the board
D4: U3.6 (A); also elsewhere on the board
D4_IO: U3.15 (B); also elsewhere on the board
D5: U3.7 (A); also elsewhere on the board
D5_IO: U3.14 (B); also elsewhere on the board
D6: U3.8 (A); also elsewhere on the board
D6_IO: U3.13 (B); also elsewhere on the board
D7: U3.9 (A); also elsewhere on the board
D7_IO: U3.12 (B); also elsewhere on the board
DMA: U6.7 (A); also elsewhere on the board
DMA_IO: U6.14 (B); also elsewhere on the board
EEPROM_PGM: U6.6 (A); also elsewhere on the board
EEPROM_PGM_IO: U6.15 (B); also elsewhere on the board
GND: C8.2, C9.2, C10.2, C11.2, C12.2, C13.2, C14.2, C15.2, C16.2, C17.2, C18.2, C19.2, U1.11 (GND), U2.11 (GND), U3.11 (GND), U4.11 (GND), U5.11 (GND), U6.8 (A), U6.9 (A), U6.11 (GND); also elsewhere on the board
IRQ_COPROC: U6.5 (A); also elsewhere on the board
IRQ_COPROC_IO: U6.16 (B); also elsewhere on the board
OE: U6.4 (A); also elsewhere on the board
OE_IO: U6.17 (B); also elsewhere on the board
PA0: U4.9 (A); also elsewhere on the board
PA0_IO: U4.12 (B); also elsewhere on the board
PA1: U4.8 (A); also elsewhere on the board
PA1_IO: U4.13 (B); also elsewhere on the board
PA2: U4.7 (A); also elsewhere on the board
PA2_IO: U4.14 (B); also elsewhere on the board
PA3: U4.6 (A); also elsewhere on the board
PA3_IO: U4.15 (B); also elsewhere on the board
PA4: U4.5 (A); also elsewhere on the board
PA4_IO: U4.16 (B); also elsewhere on the board
PA5: U4.4 (A); also elsewhere on the board
PA5_IO: U4.17 (B); also elsewhere on the board
PA6: U4.3 (A); also elsewhere on the board
PA6_IO: U4.18 (B); also elsewhere on the board
PA7: U4.1 (A); also elsewhere on the board
PA7_IO: U4.20 (B); also elsewhere on the board
PB0: U5.1 (A); also elsewhere on the board
PB0_IO: U5.20 (B); also elsewhere on the board
PB1: U5.3 (A); also elsewhere on the board
PB1_IO: U5.18 (B); also elsewhere on the board
PB2: U5.4 (A); also elsewhere on the board
PB2_IO: U5.17 (B); also elsewhere on the board
PB3: U5.5 (A); also elsewhere on the board
PB3_IO: U5.16 (B); also elsewhere on the board
PB4: U5.6 (A); also elsewhere on the board
PB4_IO: U5.15 (B); also elsewhere on the board
PB5: U5.7 (A); also elsewhere on the board
PB5_IO: U5.14 (B); also elsewhere on the board
PB6: U5.8 (A); also elsewhere on the board
PB6_IO: U5.13 (B); also elsewhere on the board
PB7: U5.9 (A); also elsewhere on the board
PB7_IO: U5.12 (B); also elsewhere on the board
VCC: C8.1, C9.1, C10.1, C11.1, C12.1, C13.1, U1.2 (VCC_A), U1.10 (OE), U2.2 (VCC_A), U2.10 (OE), U3.2 (VCC_A), U3.10 (OE), U4.2 (VCC_A), U4.10 (OE), U5.2 (VCC_A), U5.10 (OE), U6.2 (VCC_A), U6.10 (OE); also elsewhere on the board
VCCIO: C14.1, C15.1, C16.1, C17.1, C18.1, C19.1, U1.19 (VCC_B), U2.19 (VCC_B), U3.19 (VCC_B), U4.19 (VCC_B), U5.19 (VCC_B), U6.19 (VCC_B); also elsewhere on the board
WE: U6.1 (A); also elsewhere on the board
WE_IO: U6.20 (B); also elsewhere on the board

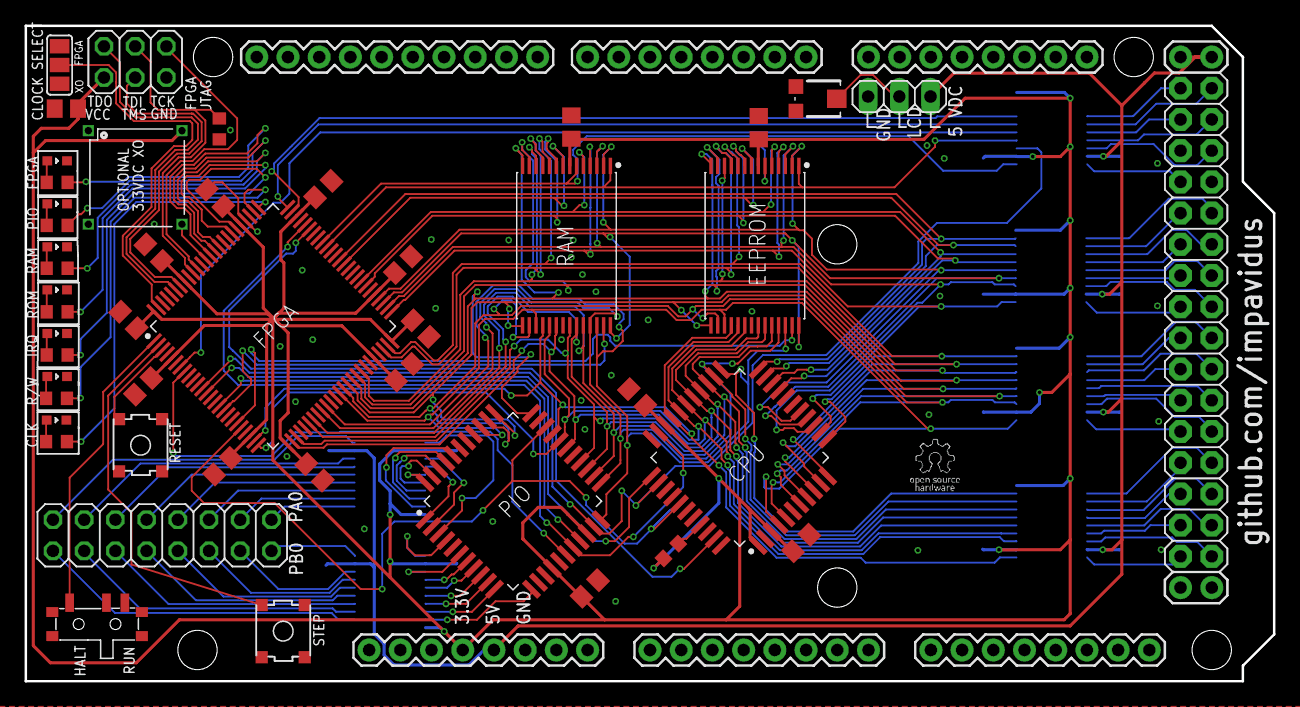
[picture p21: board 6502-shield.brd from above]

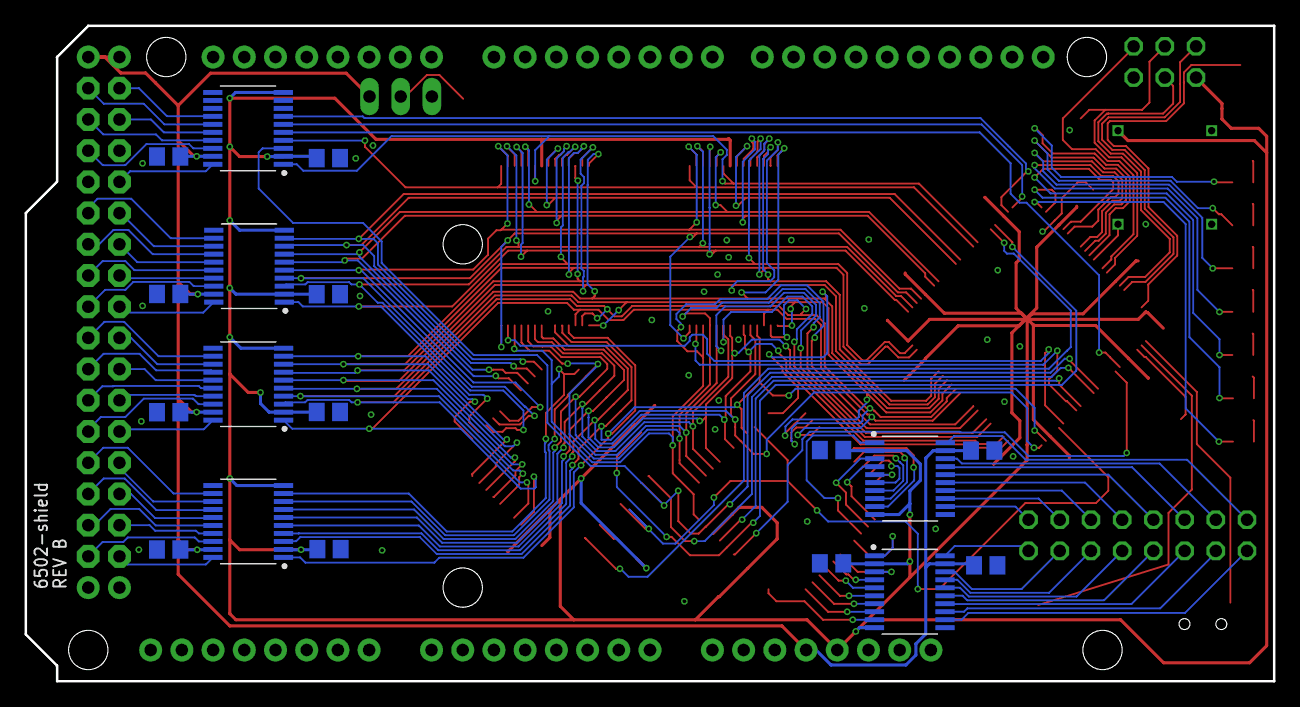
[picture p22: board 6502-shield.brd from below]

Board: 2 copper layers, 101.6 x 53.3 mm, 66 parts (18 on the bottom side), 128 nets.

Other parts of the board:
U$1: OSHW_LOGO; OSHW_LOGO@1

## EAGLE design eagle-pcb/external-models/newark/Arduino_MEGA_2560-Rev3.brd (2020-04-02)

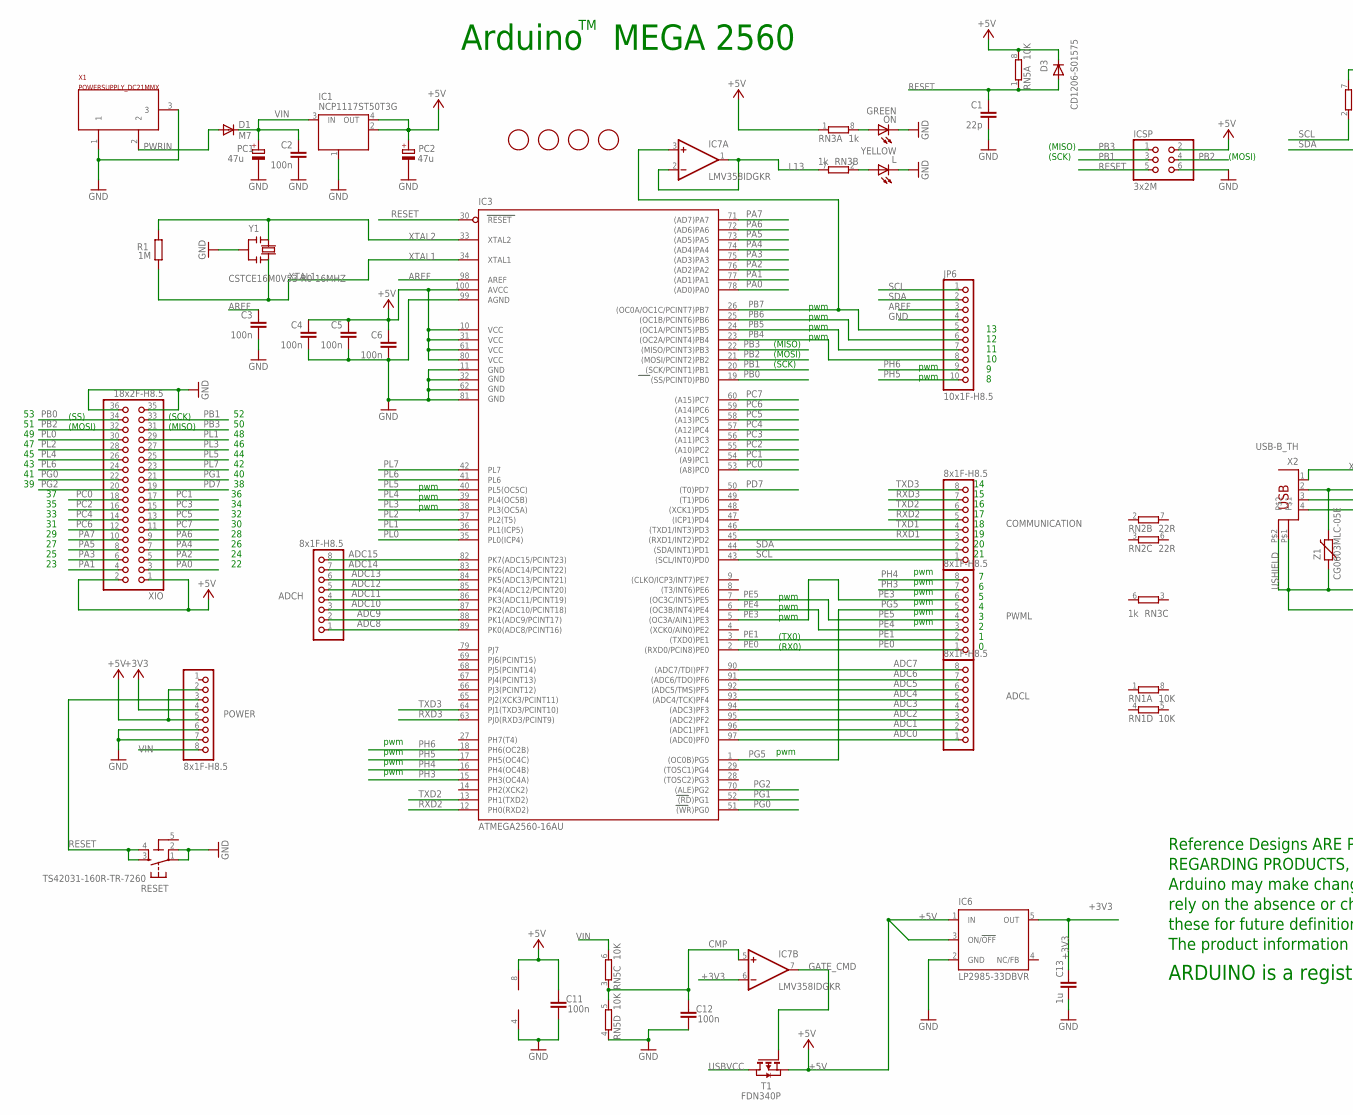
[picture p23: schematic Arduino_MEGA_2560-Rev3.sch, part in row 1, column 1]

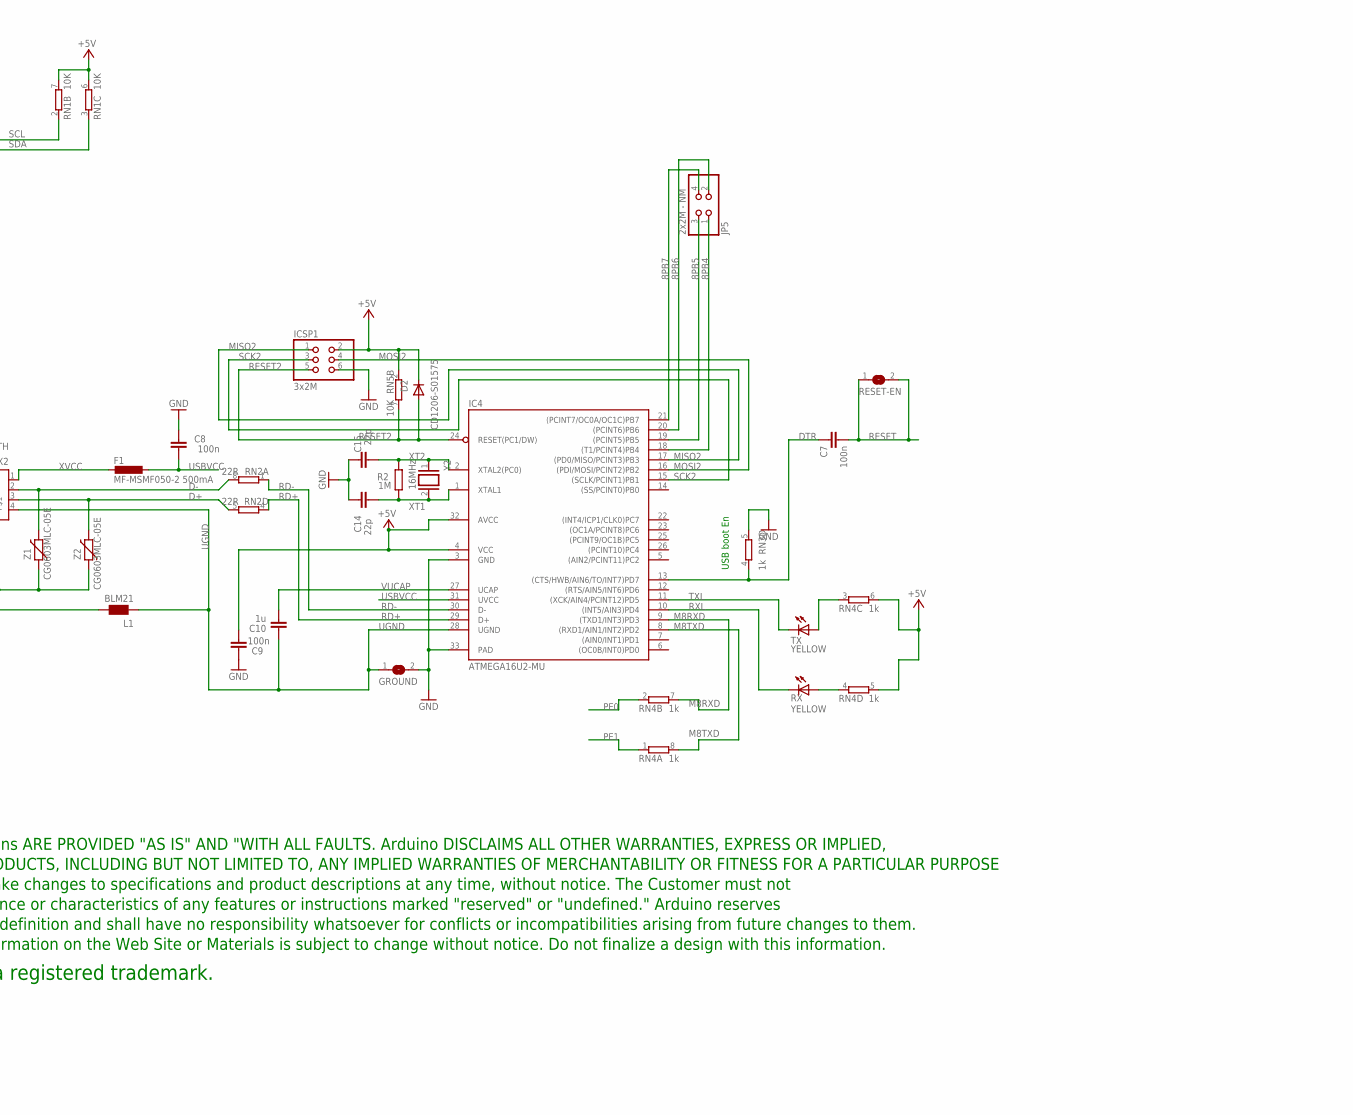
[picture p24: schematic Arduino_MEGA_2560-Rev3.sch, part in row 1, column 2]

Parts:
ADCH: 8x1F-H8.5; 1X08
ADCL: 8x1F-H8.5; 1X08
C1, C14, C15: 22p; C0603-ROUND
C2, C3, C4, C5, C6, C7, C8, C9, C11, C12: 100n; C0603-ROUND
C10, C13: 1u; C0603-ROUND
COMMUNICATION: 8x1F-H8.5; 1X08
D1: M7; SMB
D2, D3: CD1206-S01575; MINIMELF
F1: MF-MSMF050-2 500mA; L1812
FD1, FD2, FD3, FD4: FIDUCIALMOUNT; FIDUCIA-MOUNT
GROUND: SJ
IC1: NCP1117ST50T3G; SOT223
IC3: ATMEGA2560-16AU; TQFP100
IC4: ATMEGA16U2-MU; MLF32
IC6: LP2985-33DBVR; SOT23-DBV
IC7: LMV358IDGKR; MSOP08
ICSP, ICSP1: 3x2M; 2X03
JP5: 2x2M - NM; 2X02
JP6: 10x1F-H8.5; 1X10
L: YELLOW; CHIP-LED0805
L1: BLM21; 0805
ON: GREEN; CHIP-LED0805
PC1, PC2: 47u; PANASONIC_D
POWER: 8x1F-H8.5; 1X08
PWML: 8x1F-H8.5; 1X08
R1, R2: 1M; R0603-ROUND
RESET: TS42031-160R-TR-7260; TS42
RESET-EN: SJ
RN1, RN5: 10K; CAT16
RN2: 22R; CAY16
RN3, RN4: 1k; CAY16
RX: YELLOW; CHIP-LED0805
T1: FDN340P; SOT-23
TX: YELLOW; CHIP-LED0805
U$1: DISCLAIMER
X1: POWERSUPPLY_DC21MMX; POWERSUPPLY_DC-21MM
X2: USB-B_TH; PN61729
XIO: 18x2F-H8.5; 2X18
Y1: CSTCE16M0V53-R0 16MHZ; RESONATOR
Y2: 16MHz; QS
Z1, Z2: CG0603MLC-05E; CT/CN0603

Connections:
5-GND: RESET.5 (5-GND)
8PB4: IC4.18 ((T1/PCINT4)PB4), JP5.1
8PB5: IC4.19 ((PCINT5)PB5), JP5.3
8PB6: IC4.20 ((PCINT6)PB6), JP5.2
8PB7: IC4.21 ((PCINT7/OC0A/OC1C)PB7), JP5.4
+3V3: C13.2, IC6.5 (OUT), IC7.6 (-IN), POWER.4
+5V: C4.1, C5.1, C6.1, C9.1, C11.2, D2.C, D3.C, IC1.2 (OUT), IC1.4 (OUT), IC3.10 (VCC), IC3.31 (VCC1), IC3.61 (VCC2), IC3.80 (VCC3), IC3.100 (AVCC), IC4.4 (VCC), IC4.32 (AVCC), IC6.1 (IN), IC6.3 (ON/!OFF), IC7.8 (V+), ICSP.2, ICSP1.2, PC2.+, POWER.2, POWER.5, RN1.6 (2), RN1.7 (2), RN3.1, RN4.5 (2), RN4.6 (2), RN5.2 (1), RN5.8 (2), T1.2 (S), XIO.1, XIO.2
ADC0: ADCL.1, IC3.97 ((ADC0)PF0)
ADC1: ADCL.2, IC3.96 ((ADC1)PF1)
ADC2: ADCL.3, IC3.95 ((ADC2)PF2)
ADC3: ADCL.4, IC3.94 ((ADC3)PF3)
ADC4: ADCL.5, IC3.93 ((ADC4/TCK)PF4)
ADC5: ADCL.6, IC3.92 ((ADC5/TMS)PF5)
ADC6: ADCL.7, IC3.91 ((ADC6/TDO)PF6)
ADC7: ADCL.8, IC3.90 ((ADC7/TDI)PF7)
ADC8: ADCH.1, IC3.89 (PK0(ADC8/PCINT16))
ADC9: ADCH.2, IC3.88 (PK1(ADC9/PCINT17))
ADC10: ADCH.3, IC3.87 (PK2(ADC10/PCINT18))
ADC11: ADCH.4, IC3.86 (PK3(ADC11/PCINT19))
ADC12: ADCH.5, IC3.85 (PK4(ADC12/PCINT20))
ADC13: ADCH.6, IC3.84 (PK5(ADC13/PCINT21))
ADC14: ADCH.7, IC3.83 (PK6(ADC14/PCINT22))
ADC15: ADCH.8, IC3.82 (PK7(ADC15/PCINT23))
AREF: C3.1, IC3.98 (AREF), JP6.3
CMP: C12.2, IC7.5 (+IN), RN5.3 (1), RN5.5 (2)
D+: RN2.5 (2), X2.3, Z2.2
D-: RN2.8 (2), X2.2, Z1.2
DTR: C7.1, IC4.13 ((CTS/HWB/AIN6/TO/INT7)PD7), RN3.4 (1)
GATE_CMD: IC7.7 (OUT), T1.3 (G)
GND: C1.2, C2.2, C3.2, C4.2, C5.2, C6.2, C8.2, C9.2, C11.1, C12.1, C13.1, C14.2, C15.2, GROUND.2, IC1.1 (GND/ADJ), IC3.11 (GND), IC3.32 (GND1), IC3.62 (GND2), IC3.81 (GND3), IC3.99 (AGND), IC4.3 (GND), IC4.33 (PAD), IC6.2 (GND), IC7.4 (V-), ICSP.6, ICSP1.6, JP6.4, L.C, ON.C, PC1.-, PC2.-, POWER.6, POWER.7, RESET.1, RESET.2, RN3.5 (2), RN5.4 (1), X1.1, X1.3, XIO.35, XIO.36, Y1.2
L13: IC7.1 (OUT), IC7.2 (-IN), RN3.7 (2)
M8RXD: IC4.9 ((TXD1/INT3)PD3), RN4.7 (2)
M8TXD: IC4.8 ((RXD1/AIN1/INT2)PD2), RN4.8 (2)
MISO2: IC4.17 ((PD0/MISO/PCINT3)PB3), ICSP1.1
MOSI2: IC4.16 ((PDI/MOSI/PCINT2)PB2), ICSP1.4
unnamed: L.A, RN3.2 (1)
unnamed: ON.A, RN3.8 (2)
unnamed: RN4.4 (1), RX.A
unnamed: RN4.3 (1), TX.A
PA0: IC3.78 ((AD0)PA0), XIO.3
PA1: IC3.77 ((AD1)PA1), XIO.4
PA2: IC3.76 ((AD2)PA2), XIO.5
PA3: IC3.75 ((AD3)PA3), XIO.6
PA4: IC3.74 ((AD4)PA4), XIO.7
PA5: IC3.73 ((AD5)PA5), XIO.8
PA6: IC3.72 ((AD6)PA6), XIO.9
PA7: IC3.71 ((AD7)PA7), XIO.10
PB0: IC3.19 ((SS/PCINT0)PB0), XIO.34
PB1: IC3.20 ((SCK/PCINT1)PB1), ICSP.3, XIO.33
PB2: IC3.21 ((MOSI/PCINT2)PB2), ICSP.4, XIO.32
PB3: IC3.22 ((MISO/PCINT3)PB3), ICSP.1, XIO.31
PB4: IC3.23 ((OC2A/PCINT4)PB4), JP6.8
PB5: IC3.24 ((OC1A/PCINT5)PB5), JP6.7
PB6: IC3.25 ((OC1B/PCINT6)PB6), JP6.6
PB7: IC3.26 ((OC0A/OC1C/PCINT7)PB7), IC7.3 (+IN), JP6.5
PC0: IC3.53 ((A8)PC0), XIO.18
PC1: IC3.54 ((A9)PC1), XIO.17
PC2: IC3.55 ((A10)PC2), XIO.16
PC3: IC3.56 ((A11)PC3), XIO.15
PC4: IC3.57 ((A12)PC4), XIO.14
PC5: IC3.58 ((A13)PC5), XIO.13
PC6: IC3.59 ((A14)PC6), XIO.12
PC7: IC3.60 ((A15)PC7), XIO.11
PD7: IC3.50 ((T0)PD7), XIO.19
PE0: IC3.2 ((RXD0/PCIN8)PE0), PWML.1, RN4.2 (1)
PE1: IC3.3 ((TXD0)PE1), PWML.2, RN4.1
PE3: IC3.5 ((OC3A/AIN1)PE3), PWML.6
PE4: IC3.6 ((OC3B/INT4)PE4), PWML.3
PE5: IC3.7 ((OC3C/INT5)PE5), PWML.4
PG0: IC3.51 ((WR)PG0), XIO.22
PG1: IC3.52 ((RD)PG1), XIO.21
PG2: IC3.70 ((ALE)PG2), XIO.20
PG5: IC3.1 ((OC0B)PG5), PWML.5
PH3: IC3.15 (PH3(OC4A)), PWML.7
PH4: IC3.16 (PH4(OC4B)), PWML.8
PH5: IC3.17 (PH5(OC4C)), JP6.10
PH6: IC3.18 (PH6(OC2B)), JP6.9
PL0: IC3.35 (PL0(ICP4)), XIO.30
PL1: IC3.36 (PL1(ICP5)), XIO.29
PL2: IC3.37 (PL2(T5)), XIO.28
PL3: IC3.38 (PL3(OC5A)), XIO.27
PL4: IC3.39 (PL4(OC5B)), XIO.26
PL5: IC3.40 (PL5(OC5C)), XIO.25
PL6: IC3.41 (PL6), XIO.24
PL7: IC3.42 (PL7), XIO.23
PWRIN: D1.A, X1.2
RD+: IC4.29 (D+), RN2.4 (1)
RD-: IC4.30 (D-), RN2.1
RESET: C1.1, C7.2, D3.A, IC3.30 (RESET), ICSP.5, POWER.3, RESET.3, RESET.4, RESET-EN.1, RESET-EN.2, RN5.1
RESET2: D2.A, IC4.24 (RESET(PC1/DW)), ICSP1.5, RN5.7 (2)
RXD1: COMMUNICATION.3, IC3.45 ((RXD1/INT2)PD2)
RXD2: COMMUNICATION.5, IC3.12 (PH0(RXD2))
RXD3: COMMUNICATION.7, IC3.63 (PJ0(RXD3/PCINT9))
RXL: IC4.10 ((INT5/AIN3)PD4), RX.C
SCK2: IC4.15 ((SCLK/PCINT1)PB1), ICSP1.3
SCL: COMMUNICATION.1, IC3.43 ((SCL/INT0)PD0), JP6.1, RN1.2 (1)
SDA: COMMUNICATION.2, IC3.44 ((SDA/INT1)PD1), JP6.2, RN1.3 (1)
TXD1: COMMUNICATION.4, IC3.46 ((TXD1/INT3)PD3)
TXD2: COMMUNICATION.6, IC3.13 (PH1(TXD2))
TXD3: COMMUNICATION.8, IC3.64 (PJ1(TXD3/PCINT10))
TXL: IC4.11 ((XCK/AIN4/PCINT12)PD5), TX.C
UGND: C10.2, GROUND.1, IC4.28 (UGND), L1.1, X2.4
USBVCC: C8.1, F1.1, IC4.31 (UVCC), T1.1 (D)
USHIELD: L1.2, X2.P$1, X2.P$2, Z1.1, Z2.1
VIN: C2.1, D1.C, IC1.3 (IN), PC1.+, POWER.8, RN5.6 (2)
VUCAP: C10.1, IC4.27 (UCAP)
XT1: C14.1, IC4.1 (XTAL1), R2.1, Y2.2
XT2: C15.1, IC4.2 (XTAL2(PC0)), R2.2, Y2.1
XTAL1: IC3.34 (XTAL1), R1.1, Y1.3
XTAL2: IC3.33 (XTAL2), R1.2, Y1.1
XVCC: F1.2, X2.1

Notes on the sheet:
Arduino MEGA 2560
(SCK)
(MISO)
(MOSI)
pwm
(TX0)
(RX0)
(SS)
USB boot En

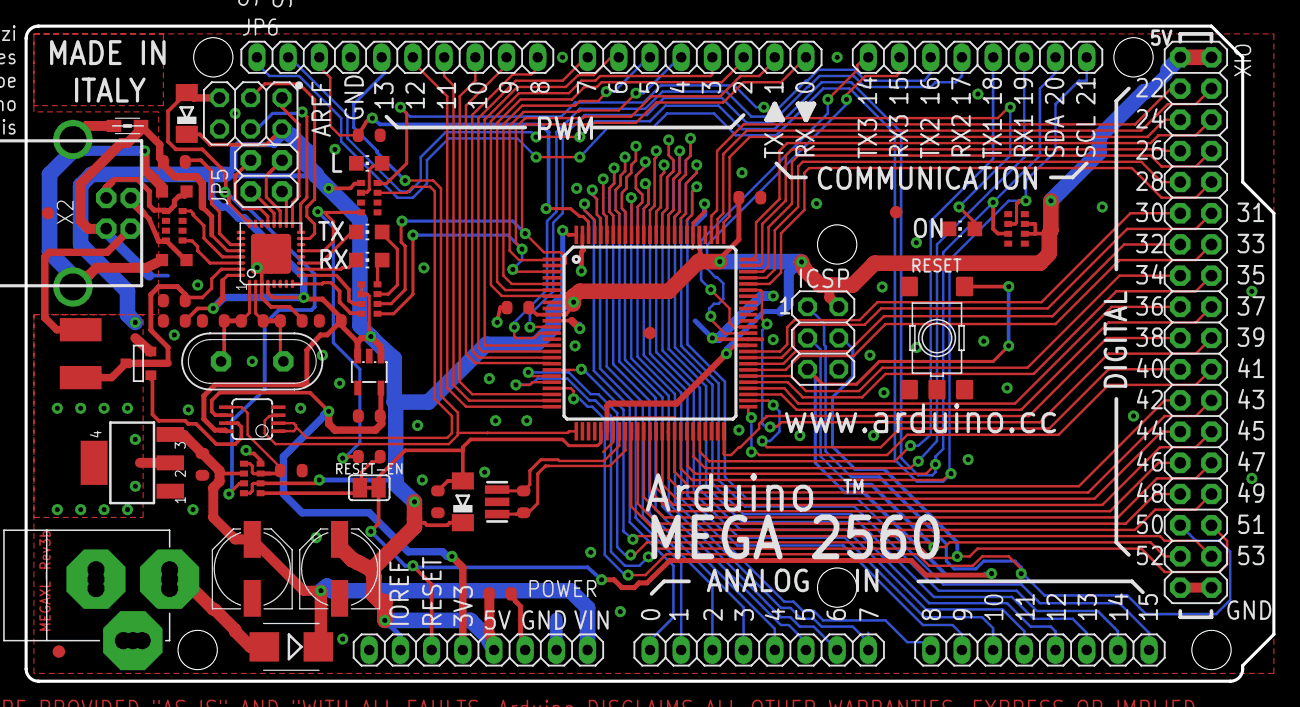
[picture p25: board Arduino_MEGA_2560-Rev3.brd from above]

Board: 2 copper layers, 101.6 x 53.3 mm, 63 parts (1 on the bottom side), 110 nets.

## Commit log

2020-03-23 Basic project setup and a library. Added some stuff to the library.
    [6502-shield.sch, AT28C256-15TU.stl, AT28C256-15TU.stp]
2020-04-02 Dead end =(
    [6502-shield.sch, AT28C256-15TU.stl, AT28C256-15TU.stp]
2020-04-02 forgot some stuff
    [6502-shield.brd, Arduino_MEGA_2560-Rev3.brd, Arduino_MEGA_2560-Rev3.sch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]
2020-04-02 pulling the plug on discrete timers and gates to replace with FPGA =( Can't make it fit on a shield with a 2 layer pwb.
    [6502-shield v38.f3d, 6502-shield v38.step]
2020-04-02 added lattice machx02-256 FPGA in tqfp100 package - symbol, footprint, 3d model
    [6502-shield.brd, 6502-shield.sch]
2020-04-02 adding drc files with rules suitable for reasonable manufacturing, same with rules for gerbers in cam file
2020-04-05 got the fpga based design done (first pass). Notional parts placement, no routing.
    [6502-shield.brd, 6502-shield.sch]
2020-04-05 apparently I'm not gitting it... git it? git it? oh boy...
    [ACDX02-41.STEP, ACSX02-41.STEP, SSW-110-02-T-D.stp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]
2020-04-10 fully routed, getting close
    [6502-shield.brd, 6502-shield.sch]
2020-04-10 This should be ready to send out.
    [6502-shield v38.f3d, 6502-shield v38.step, 6502-shield v73.f3d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]
2020-04-10 updated gitignore to not ignore cam files
    [drill_1_16.xln]
2020-04-23 Fixed problems with FPGA pinout in component library, updated schematic and cleaned it up a bunch. Fixed external clock not coming into FPGA on dedicated clock net pin. More schematic work on the lis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
    [6502-shield.brd, 6502-shield.sch]
2020-04-25 Bunch of work on rev b. but more to do.
    [6502-shield.brd, 6502-shield.sch]
2020-04-26 More routing work on the pcb, lots more left... yay =/
    [6502-shield.brd, 6502-shield.sch]
2020-04-26 The fpga is now fully broken out and mostly routed, edges of board are routed so pretty much just the busses left to do.
    [6502-shield.brd]
2020-04-26 more routing work on the pcb but not quite there yet.
    [6502-shield.brd]
2020-04-28 Board is routed w/ no erc or drc errors.
    [6502-shield.brd, 6502-shield.sch]
2020-04-30 Made some tweaks and random clean up. Updating the images and a system block diagram.
    [6502-shield.brd, 6502-shield.sch]
2020-04-30 Generated new gerbers, bom, pick & place. Generated new 3d models.
    [6502-shield v73.f3d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]
2020-05-03 fixed. verified footprint with the printer. still need to generate new camoutputs, etc.
    [6502-shield.brd, 6502-shield.sch]
2020-05-04 Overlooked that tactile switch pads were very small for hand soldering so enlarged them. Created new models, gerbers, and images.
    [6502-shield.brd, 6502-shield.sch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]
2020-05-05 Added some more silkscreen
    [6502-shield.brd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]
2020-05-19 This commit (and branch) got a little bigger than planned. Added bus activity monitor component to debounce switches and drive leds with pwm - both through a register interface to the rest of the des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

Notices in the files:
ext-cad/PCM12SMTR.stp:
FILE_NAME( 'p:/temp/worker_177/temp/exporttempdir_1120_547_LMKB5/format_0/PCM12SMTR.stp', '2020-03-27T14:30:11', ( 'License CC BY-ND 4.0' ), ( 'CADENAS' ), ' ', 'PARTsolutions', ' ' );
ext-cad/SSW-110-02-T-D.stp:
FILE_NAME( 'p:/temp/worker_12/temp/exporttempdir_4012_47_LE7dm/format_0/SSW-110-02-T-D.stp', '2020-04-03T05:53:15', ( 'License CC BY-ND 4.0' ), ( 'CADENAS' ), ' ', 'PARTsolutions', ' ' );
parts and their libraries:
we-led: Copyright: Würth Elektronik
